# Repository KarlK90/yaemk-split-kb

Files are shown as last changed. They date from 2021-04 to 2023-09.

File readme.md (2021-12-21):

<!--
SPDX-FileCopyrightText: 2021 Stefan Kerkmann <karlk90@pm.me>

SPDX-License-Identifier: CC-BY-SA-4.0
-->

# Yet Another Ergonomic Mechanical Keyboard

[](
    https://api.reuse.software/info/github.com/KarlK90/yaemk-split-kb)

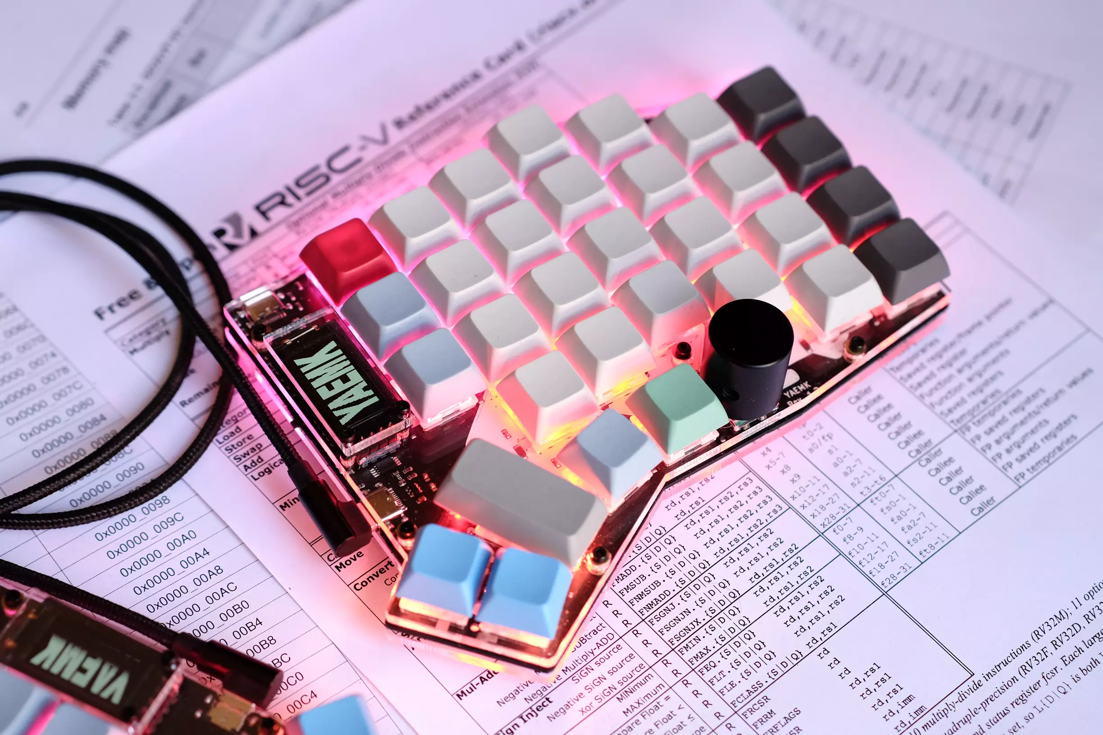
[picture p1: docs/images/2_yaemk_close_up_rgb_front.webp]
YAEMK Front


# [>>> VISIT THE WEBSITE <<<](https://karlk90.github.io/yaemk-split-kb/)

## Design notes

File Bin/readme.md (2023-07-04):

<!--
SPDX-FileCopyrightText: 2021 Stefan Kerkmann <karlk90@pm.me>
SPDX-License-Identifier: CC-BY-SA-4.0
-->

# Test Firmware Files

These firmware images are meant for easy testing purposes
only when building your own YAEMK.
Successfully flashed firmware will have:
- QWERTY layout
- Both Switch and Backlight LEDs are in rainbow mode
- Potentiometers are used for scrolling
- OLED display shows "YAEMK" logo

## Flashing ARM

After connecting the board to PC nothing will show up. On a Linux system you
can see following errors in `dmesg`:

    [   73.941437] usb 1-4: device descriptor read/64, error -71

The board need to be switched to DFU Mode in which it can be flashed:
* Hold Reset/DFU switch with USB-cable plugged in
  until the keyboard registers as `STMicroelectronics STM Device in DFU Mode`
* Flash firmware with dfu-util using this command:
  * `dfu-util -d 0483:df11 -s 0x08000000:leave -D karlk90_yaemk_arm_default.bin -w`

If `dfu-util` shows error that multiple DFU were found. Then, find one with
"Internal Flash" in name:

    > sudo dfu-util --list | grep "Internal Flash"
    Found DFU: [0483:df11] ver=2200, devnum=9, cfg=1, intf=0, path="1-4", alt=0, name="@Internal Flash  /0x08000000/128*0002Kg", serial="206B306A2034"
                                                      ^^^^^^              ^^^^^

Add `-i` and `-a` arguments with -i set to `intf` value and -a set to `alt`
value:

    > sudo dfu-util -d 0483:df11 -s 0x08000000:leave -D karlk90_yaemk_arm_via.bin -w -i 0 -a 0

## Flashing RISC-V

**You need a recent version of `dfu-util`
that has a fix for the DFU bootloader of the GD32VF103.
Follow these [instructions](
http://dfu-util.sourceforge.net/build.html) for your OS.**

* Hold the Reset/DFU switch with the USB cable plugged in,
  detach cable and re-plug immediately release the button shortly after.
  Your keyboard shows up as `GDMicroelectronics GD32 DFU Bootloader`.
* Flash firmware with dfu-util using this command:
  * `dfu-util -d 28e9:0189 -s 0x08000000:leave -D karlk90_yaemk_riscv_default.bin -w`

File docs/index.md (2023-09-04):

<!--
SPDX-FileCopyrightText: 2021 Stefan Kerkmann <karlk90@pm.me>

SPDX-License-Identifier: CC-BY-SA-4.0
-->

# Features of the YAEMK

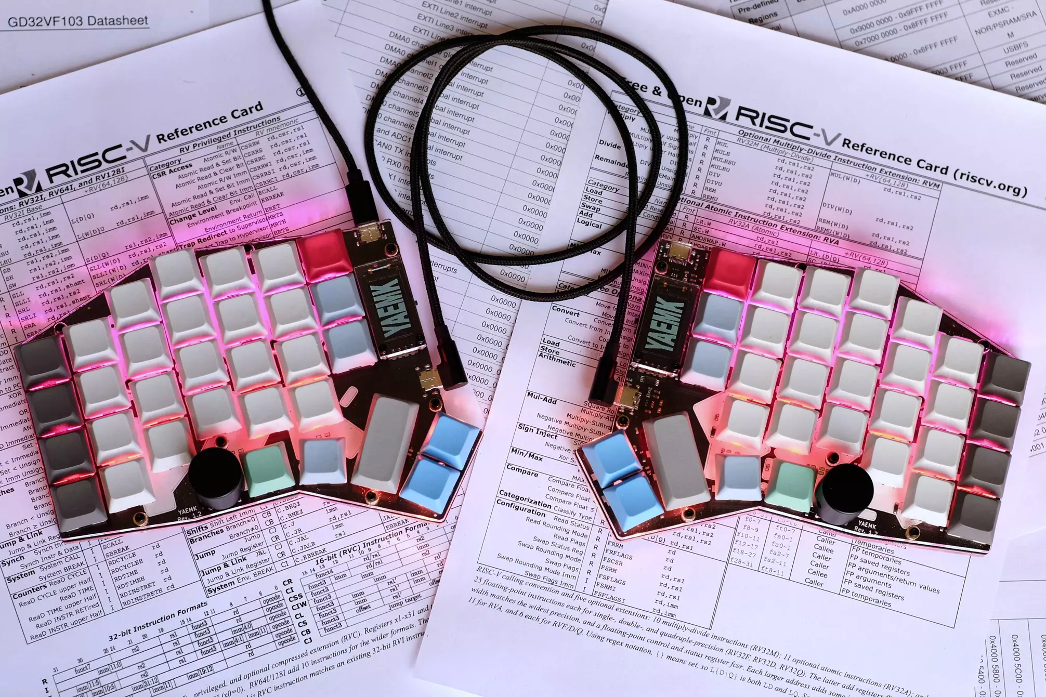
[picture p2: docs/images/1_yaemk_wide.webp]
YAEMK wide view

YAEMK close up front
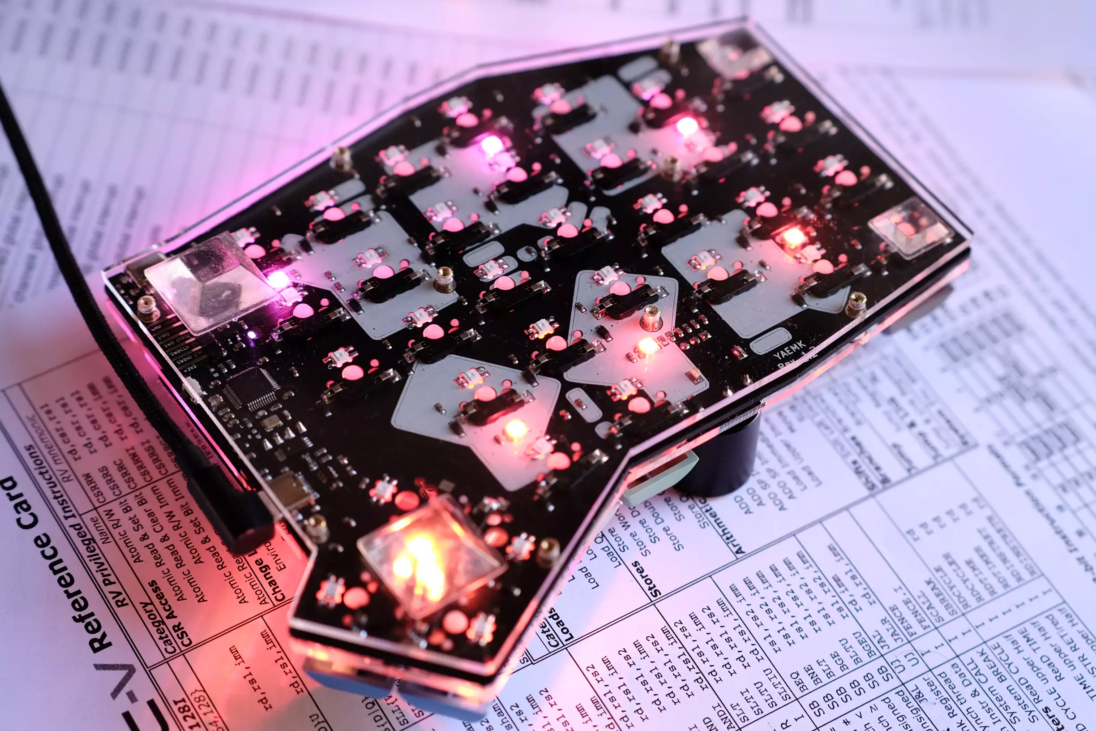
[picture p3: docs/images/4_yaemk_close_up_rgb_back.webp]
YAEMK close up back


* Split-Keyboard with 5 rows by 8 columns matrix with columnar stagger.
  Key layout testers for print ([A4](yaemk_layout_tester_a4.pdf)
  and [Letter](yaemk_layout_tester_letter.pdf)) available!
* All 64 to 66 Keys are MX-compatible and hot-swapable.
* The thumb-cluster is configurable in 4 different configurations,
  just solder the hot-swap sockets to your needs.
  * 4x1u, 2x2u, 2u+2x1u or 2x1u+2u configuration possible.
  * Inspired by the marvelous [Kyria](
    https://splitkb.com/collections/keyboard-kits/products/kyria-pcb-kit)
    from Thomas Baart!
* On-board ARM microcontroller (STM32F303CCT6) or RISC-V microcontroller (GD32VF103CBT6)
  * **Worlds first RISC-V (Split-)Keyboard!**
* Fully supported by QMK Firmware
* Per-Key RGB back lighting with 66 easy to solder SK6812-mini-e LEDs
* Underglow RGB with 14 SMD SK6812-mini LEDs
* USB-C Hot-plugable sockets for USB connection,
  and split communication between the halves
* Two 0.96" OLED displays for comprehensive information (I2C SH1107 64x128 Pixel)
* 2 x Rotary encoders for scrolling, volume changes etc.
* On-board 64KB I2C EEPROM for settings, keymaps etc.
* Open-Source, single PCB design for both sides.
  * PCB SMT assembly files for JLCPCB in the repo!
* 2-plate acrylic case files available.

## Table of contents

* TOC
{:toc}

## YAEMK Key layout testers

Key layout

Find out if building a YAEMK fits your hands, available in:

* [A4 Key layout tester](yaemk_layout_tester_a4.pdf)
* [Letter Key layout tester](yaemk_layout_tester_letter.pdf).

## Thumbcluster configurations

Four thumbcluster configurations are possible,
depending on the location of the soldered hot swap sockets.
Every configuration has a dedicated top plate for the case in the repository.

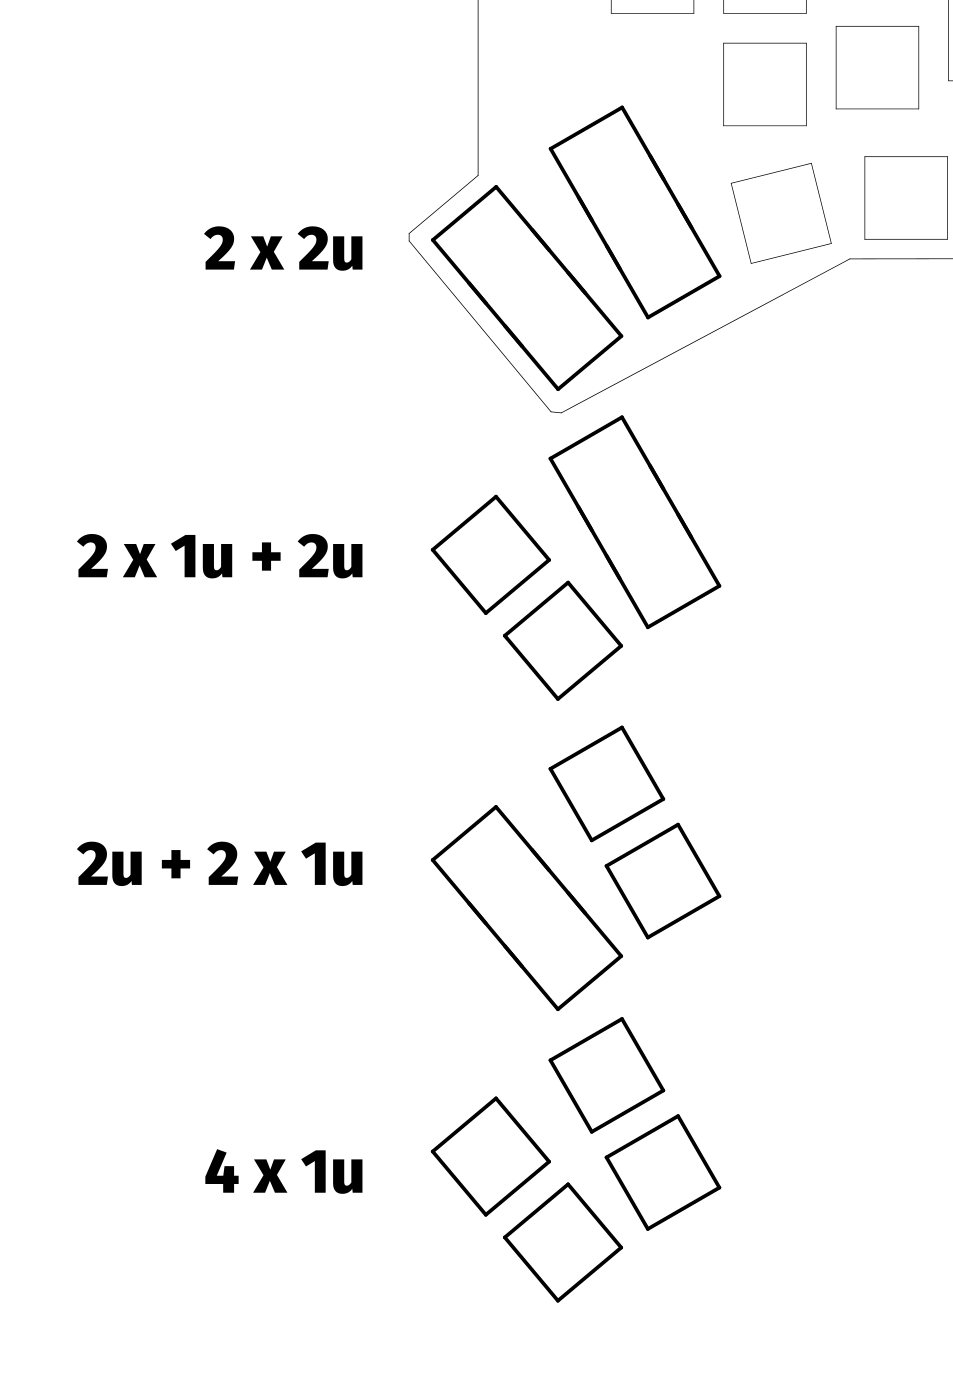
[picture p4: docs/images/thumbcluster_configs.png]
Supported thumbcluster configurations


# Build Guide

**DISCLAIMER: At the time of writing (11th of May 2021),
there is a world wide, on-going semiconductor shortage.
Both MCUs of the YAEMK,
the [STM32F303CCT6](
https://www.oemsecrets.com/compare/1/EUR/STM32F303CCT6) and
[GD32VF103CBT6](https://www.oemsecrets.com/compare/1/EUR/GD32VF103CBT6)
are affected by this shortage
and are out of stock.
The GD32VF103CBT6 can be sourced from devboards like the Sipeed Longan Nano,
but desoldering requires a hot air station.
Also the GD32VF103 requires installing a [GCC RISC-V toolchain](
https://www.embecosm.com/resources/tool-chain-downloads/#riscv-stable),
a recent `dfu-util` with fixes for the DFU bootloader.**

The complete design including [schematics](https://github.com/KarlK90/yaemk-split-kb/tree/main/PCB),
[gerbers](https://github.com/KarlK90/yaemk-split-kb/tree/main/PCB/gerbers),
[pcb smt assembly files](https://github.com/KarlK90/yaemk-split-kb/tree/main/PCB/assembly)
and a [acrylic plate case](https://github.com/KarlK90/yaemk-split-kb/tree/main/Case)
are open source and available in the repository.
The complete project can be opened with the open source [KiCad EDA](https://www.kicad.org/).

> **If you have never soldered before,
> the YAEMK will be quite a challenge.
> Therefore it is recommended to buy yourself some SMD soldering practice kits
> and learn it beforehand.**

## 1 The Boards

Building your own YAEMK involves ordering the PCBs
from [JLCPCB](https://jlcpcb.com/) with PCB SMT assembly,
so nearly all components come pre-soldered.
Only through hole components, tactile-switches,
connectors and SMD components have to be soldered by you.
It is crucial to understand that the YAEMK pcb is flip able,
which means that every circuit board
can be turned once into the left or right side of your keyboard.
Depending on right or left handedness of the PCB
these components have to be soldered either on the front or back side of the pcb.
The whole process is documented in detail below.
The tools you will need are a good quality pair of tweezers,
flux, leaded solder and a temperature controlled soldering iron,
a hot air station is recommended but not strictly necessary.
For easy component location and sourcing of parts,
it is recommended to use the [interactiv HTML BOM](./yaemk_rev_1_2.html).

<iframe src="./yaemk_rev_1_2.html" width="100%" height="500px"></iframe>

### Ordering process

If you have never ordered PCBs with assembly from [JLCPCB](https://jlcpcb.com),
I highly recommend watching the steps from Phil’s Lab
in the [KiCad STM32 + USB + Buck Converter PCB Design and JLCPCB Assembly](
https://www.youtube.com/watch?v=C7-8nUU6e3E&t=9872s) video.
The default settings are mostly fine;
The changes you want to pick are the following:

#### PCB

* Use the [gerbers.zip](https://github.com/KarlK90/yaemk-split-kb/tree/main/PCB/gerbers.zip)
  file from the PCB folder for upload.
* The Gerber preview has timeouts from time to time when uploading to JLCPCB.
  Just fill a width of `166mm` and a height of `131mm`.
* 2 Layers (The video has a 4 Layer board)
* PCB Oty: As much as you like
* PCB Color: Black
* No impedance control (Option only shown in the video)
* Surface Finish:
  HASL(with lead) if you want the easiest soldering experience,
  or LeadFree HASL.
  For extra bling-bling choose ENIG gold finish.
* Remove Order Number: Yes

#### SMT Assembly

**ATTENTION: At the time of writing (11th of May 2021),
there is a world wide on-going semiconductor shortage,
both MCUs of the YAEMK the [STM32F303CCT6](
https://www.oemsecrets.com/compare/1/EUR/STM32F303CCT6)
and [GD32VF103CBT6](https://www.oemsecrets.com/compare/1/EUR/GD32VF103CBT6)
are affected of this shortage and are out of stock.
Therefore you currently can not order the pcb with the MCU pre-soldered.
I was not able to correct and confirm the MCU orientation,
it is likely rotated in correctly.
As soon as the MCU is in stock again this will be addressed.**

* Assemble top side
* SMT Oty: As much as you like
* Tooling holes: Added by Customer
* Add BOM file:
  the file is [PCB/assembly/YAEMK_bom.csv](
  https://github.com/KarlK90/yaemk-split-kb/blob/main/PCB/assembly/YAEMK_bom.csv)
  * If the default EEPROM and Opamp are out of stock,
    you can try the alternate BOM file:
    the file is [PCB/assembly/YAEMK_bom_alternate_eeprom_and_opamp.csv](
    https://github.com/KarlK90/yaemk-split-kb/blob/main/PCB/assembly/YAEMK_bom_alternate_eeprom_and_opamp.csv)
* Add CPL file: the file is [PCB/assembly/YAEMK-top-pos_corrected.csv](
  https://github.com/KarlK90/yaemk-split-kb/blob/main/PCB/assembly/YAEMK-top-pos_corrected.csv)
* If you want the GD32VF103 MCU,
  deselect `U5 STM32F303CCTx` on the *Select Parts* page.
  You have to source and solder the GD32VF103 yourself.

After placing your order you can proceed ordering the missing parts from [LCSC](https://lcsc.com/),
as they are both part of the same company,
you [can save shipping costs](https://www.lcsc.com/faqs?id=140)
when specifying your JLCPCB order number.

### Additional bill of materials for one complete Keyboard

All components that are NOT pre-soldered by [JLCPCB](https://jlcpcb.com/)
are listed in this table and have to be bought and assembled by you.
Switches and Keycaps are highly personal decision,
you find my recommendation at the bottom.
As I'm using a rather uncommon keyboard layout (K.O,Y) I stick to blank keycaps.

Personal recommendation of Aliexpress stores:

  - [Cool Jazz Store](https://cooljazz.aliexpress.com/store/1806079)
  - [KRepublic](https://kprepublic.aliexpress.com/store/3034003)

| Amount | Part | LCSC | Link |
| --- | --- | --- | --- |
| 4 | USB-C Socket Mid-mount | C168688 | [LCSC](https://lcsc.com/product-detail/USB-Connectors_Jing-Extension-of-the-Electronic-Co-C168688_C168688.html) or [Aliexpress](https://www.aliexpress.com/item/4000074094558.html) |
| 2 | Alps EC11 Rotary Encoder | C370986 | [LCSC](https://lcsc.com/product-detail/Coded-Rotary-Switches_ALPS-Electric-EC11E183440C_C370986.html) |
| 5 | LMV321 Opamp (Backup) | C686637 | [LCSC](https://lcsc.com/product-detail/Operational-Amplifier_PJSEMI-LMV321_C686637.html) |
| 66 | SK6812-mini-e (3228) RGB LEDs | - | [Aliexpress](https://www.aliexpress.com/item/4000475685852.html) |
| 14 | SK6812-mini (3535) RGB LEDs | - | [Aliexpress](https://www.aliexpress.com/item/33019583218.html) |
| 66 | Hotswap Kailh or Gateron Sockets | - | [Aliexpress](https://www.aliexpress.com/item/1005002037689483.html) |
| 2 | Encoder Knob | - | [Splitkb](https://splitkb.com/collections/keyboard-parts/products/matte-aluminium-encoder-knob) or [Aliexpress](https://www.aliexpress.com/item/32893184848.html) or [Aliexpress](https://www.aliexpress.com/item/32810522800.html) |
| 2 | 0.96" SSD1107 64x128 Display | --- | [Aliexpress](https://www.aliexpress.com/item/1005002891710621.html) |
| 2 | Blue 0603 Power LED | C72041  | [LCSC](https://lcsc.com/product-detail/Light-Emitting-Diodes-LED_0603-Blue-light_C72041.html) |
| 2 | Reset/DFU Switch | C393942 | [LCSC](https://lcsc.com/product-detail/Tactile-Switches_SHOU-HAN-TS24CA_C393942.html) |
| 2 | Display Socket | C358718 | [LCSC](https://lcsc.com/product-detail/Pin-Header-Female-Header_MINTRON-MTF185-104SY1_C358718.html) |
| 2 | Debug Pinheader (optional) | C56816  | [LCSC](https://lcsc.com/product-detail/Pin-Header-Female-Header_BOOMELE-Boom-Precision-Elec-2-54-1-6PHeader_C56816.html) |
| 66 | Switches (depending on Thumbcluster) | - | Personal recommendations [Clicky - Box Yellow](https://www.aliexpress.com/item/1005001684056035.html) or [Tactile - Boba U4 RGB](https://www.aliexpress.com/item/1005001809357064.html) or [Linear - Boba Bobbagum](https://www.aliexpress.com/item/1005001985634467.html) |
| 64-66  | 1u Keycaps (depending on Thumbcluster) | - | e.g. 1u XDA Profile caps [Aliexpress](https://www.aliexpress.com/item/1005004021955113.html) |  |
| 0-4 | 2u Keycaps (depending on Thumbcluster) | - | e.g. 2u XDA Profile caps [Aliexpress](https://www.aliexpress.com/item/1005001376888502.html) |

**Tip: Buy some excess LEDs as they are heat sensitive!**

### Placement of hotswap sockets for thumbcluster

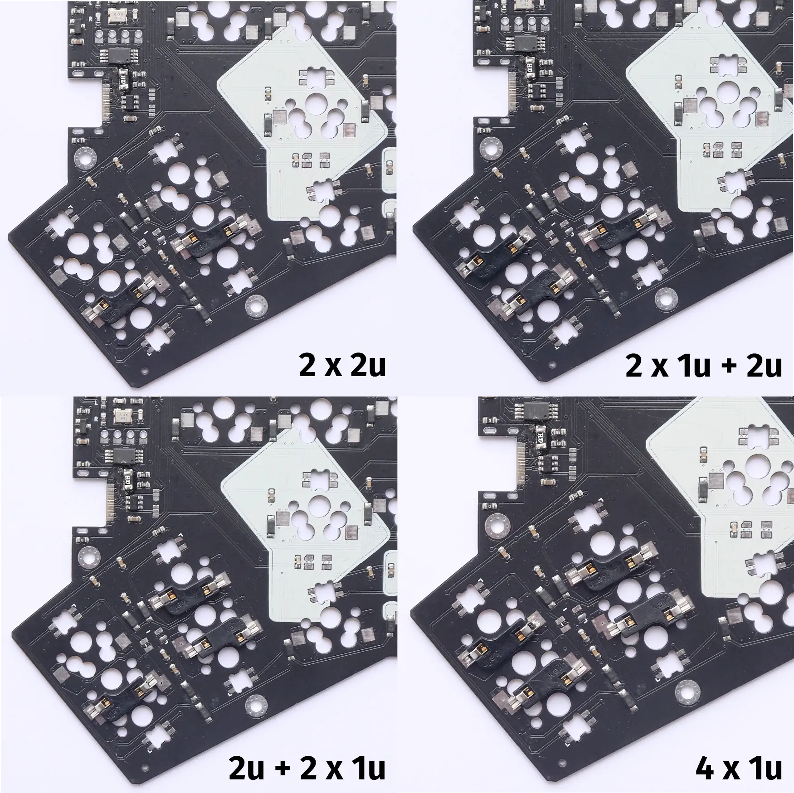
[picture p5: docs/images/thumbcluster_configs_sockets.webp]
Thumbcluster configurations sockets


### Correct orientation of hotswap sockets

Do not obstruct the middle hole with the hotswap sockets or switches will not fit!

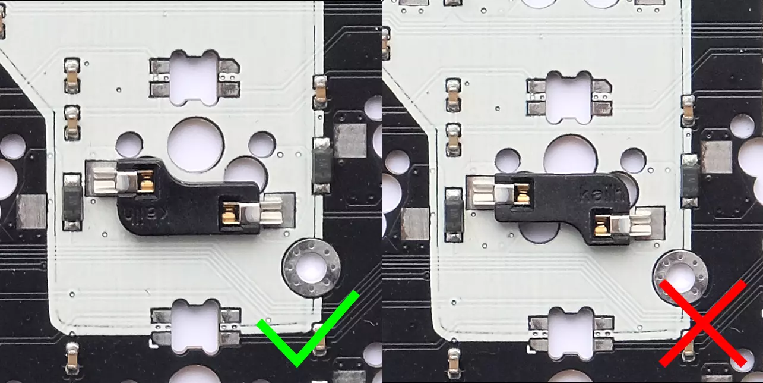
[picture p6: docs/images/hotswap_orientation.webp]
Correct orientation hotswap sockets


### Correct orientation of rgb leds

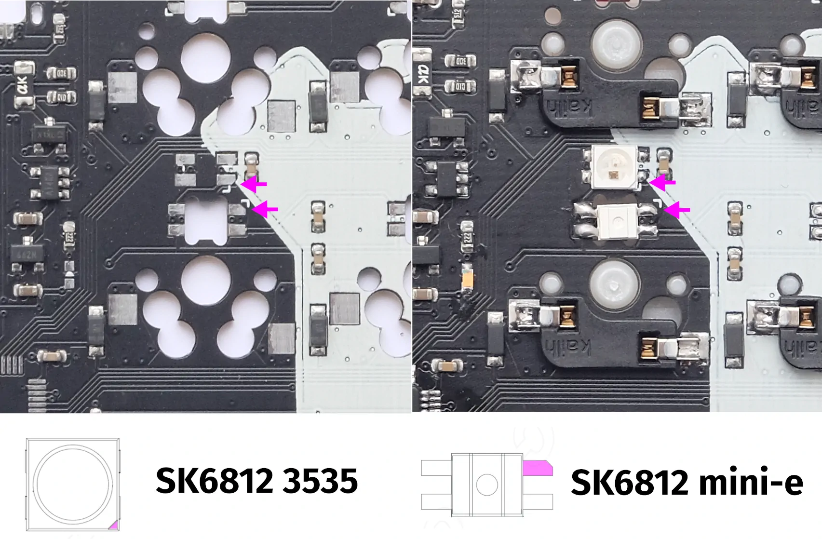
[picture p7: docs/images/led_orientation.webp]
Correct orientation of rgb leds


Every led has little chamfer that indicates the correct orientation,
match it with the chamfer on the pad of the PCB
and the little white triangle silk screened next to the pad.
Two types of leds are used on the YAEMK the first sk6812 3535 are for underglow,
there are 7 per side in total and distributed along the edges of the PCB,
it is the upper led in the picture.
They shine down on the surface the keyboard rests on.
The second type are sk6812-mini-e leds for per-key backlighting,
it is the lower led in the picture.
They shine up through the PCB,
away from the surface the keyboard rests on.

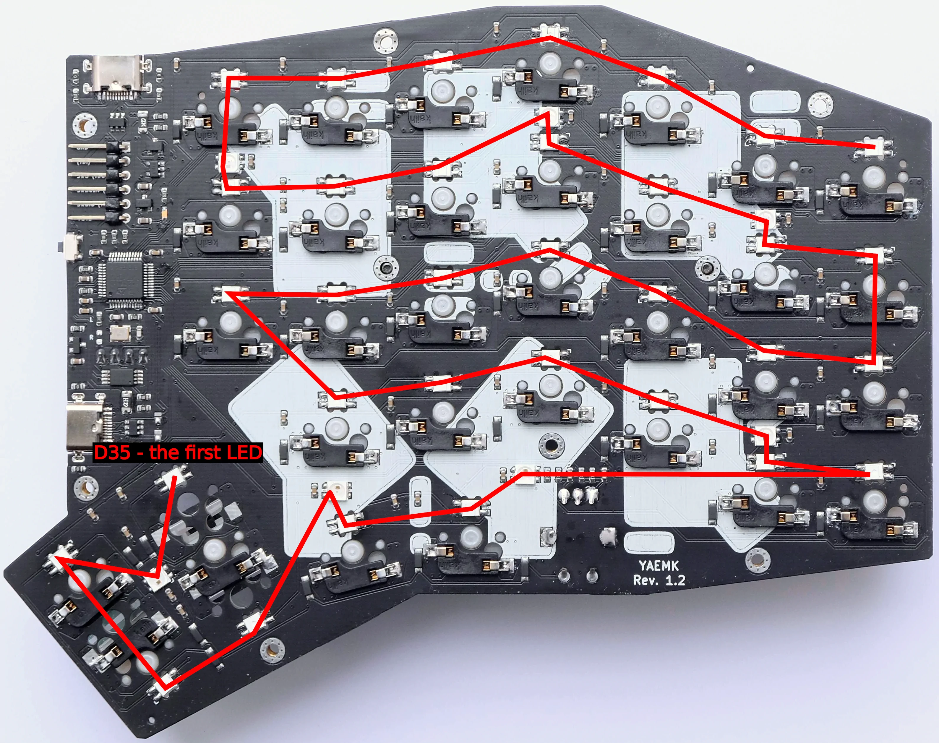
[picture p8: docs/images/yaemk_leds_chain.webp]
LED chain orientation


### Modification of SH1107 display modules

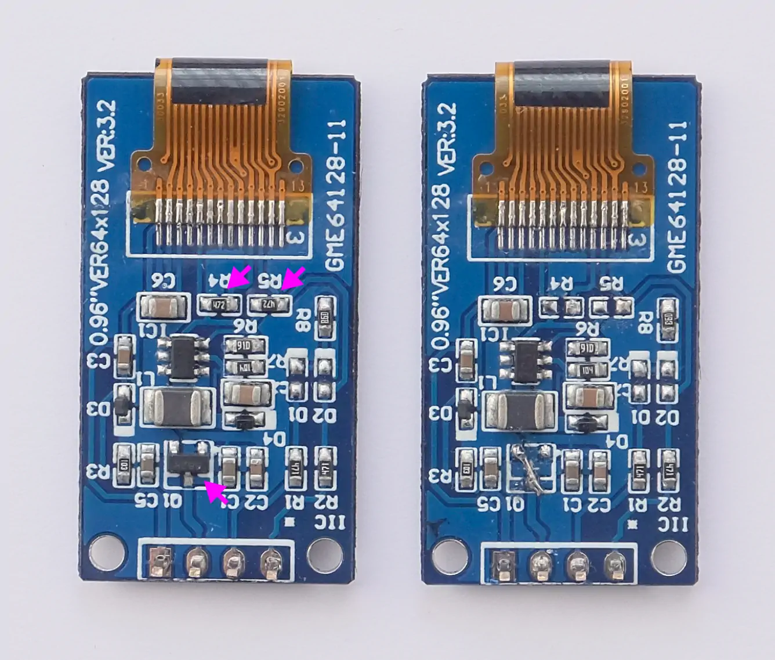
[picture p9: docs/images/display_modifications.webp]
SH1107 display module modifications


Remove the pull-up resistors `R4` and `R5` with your soldering iron,
these redundant as the YAEMK already has pull-ups in place.
Remove the low drop out (LDO) regulator `Q1`
by cutting its legs or with your soldering iron
and bridge the terminal by soldering a small piece of wire in place.
The LDO is redundant and serves no function,
as the YAEMK already supplies the display with stabilized 3.3V VDD.

### Step-by-step Instructions

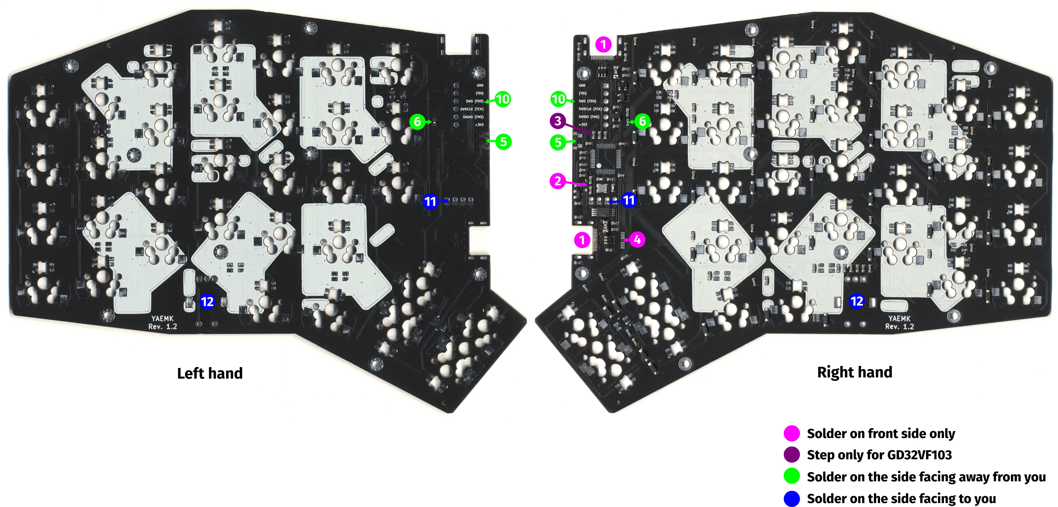
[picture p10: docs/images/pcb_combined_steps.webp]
PCBs with Step-by-step instructions


*Note: the picture shows pcbs without an mcu.*

> Emphasized text like `P1 and P2` are the component references,
> you can find them in the schematic and interactive bom.

1. Solder USB-C Sockets for USB connection and Split communications. `P1 and P2`
    * Make sure to apply enough solder
      and thoroughly wet the pins that secure the socket with the PCB.
2. Remove handedness selection resistor `R24 or R25`
    * The handedness, meaning if it is the right or left side of the keyboard,
      is determined by these resistors.
      PCBs come with both resistors soldered in place from JLCPCB.
      Keep the resistor for the side you want this PCB to be,
      e.g. keep resistor `R25` next to the little R
      if this PCB should be the right side of the keyboard
      and remove resistor `R24` next to the little L.
3. *(GD32VF103 only)* Remove USB D+ pullup resistor `R20`
4. Close split communication solder jumpers `JP1 and JP2`
    * Both halves of the YAEMK communicate via a full-duplex USART connection
      over a USB-C cable (we re-purpose the USB cable for this).
      For this to work the TX lines of one halve
      have to be connected with the RX line of the other halve.
      That's what the solder bridge is for,
      to reroute the TX line of one halve into the RX line of the other.
    * Connect the bottom pad with the middle pad on both jumpers
      via a solder bridge on the left side of the keyboard.
    * Connect the top pad with the middle pad on both jumpers
      via a solder bridge on the right side of the keyboard.
5. Solder Reset/DFU Switch on the side facing away from you. `S32`
6. Solder power LED on the side facing away from you. `D70`
    * A little triangle shows the orientation of the LED on the board,
      match this triangle with the triangle on the bottom of the led.
7. Flash the [testing firmware provided](
    https://github.com/KarlK90/yaemk-split-kb/tree/main/Bin)
    and test for successful usb connection.
8. Solder RGB LEDs on the side facing away from you.
    Make sure to [correctly orient](#correct-orientation-of-rgb-leds) them,
    as they are not the same orientation all the time.
    Use the interactive BOM when in doubt. `D35 to D76`. Check that all LEDs
    are working by connecting the board to USB (the firmware from step 7 turns
    on all the LEDs). Note that as LEDs are [connected in
    chain](#correct-orientation-of-rgb-leds)  - one dead LED leads
    to all subsequent leds being off.
9. Solder MX Hotswap Sockets on the side facing away from you.
    Decide for a [thumbcluster configuration](#placement-of-hotswap-sockets-for-thumbcluster).
    Make sure to [correctly orient](#correct-orientation-of-hotswap-sockets) them.
    `S1 to S31`
10. *(Optional)* Solder Debug Header on the side facing away from you.
    `J1`
11. Solder Display Socket on the side facing to you.
    `P3`
    * Bridge the pads next to the through holes when soldering to close the contact.
12. Solder Rotary Encoder on the side facing to you.
    `SW1`
13. Clean the Board from any residues with alcohol.
14. Modifiy the SH1107 displays by removing the pull-ups
    and the LDO as [demonstrated](#modification-of-sh1107-display-modules).
15. Trim the plastic and the pin header of the display
    so that the pcb of the display sits flush on the display socket.
16. *(Optional)* Paint the edges of the pcb with a black marker pen.
17. *(Optional)* Paint the blue display frame and pcb edges with a black marker pen.
18. Test board for full operation, see Troubleshooting notes below in case of errors:
    * Displays show YAEMK logo on startup on both halves.
    * Successful USB connection of both halves to the pc,
      regardless of plug orientation.
      Make sure that the default Layer designator "QWERTY" on the OLED
      is surrounded by two small dots.
      This indicates that this side has a USB connection.
    * Successful split connection between both halves,
      regardless of plug orientation.
      If both sides claim to have a USB connection
      ("QWERTY" on the OLED is surrounded by two small dots on both sides)
      altough one is clearly powered by the other
      and has no direct USB connection to the PC
      (the peripheral half) jump to [Peripheral half show USB connection](
      #peripheral-half-shows-usb-connection).
    * Key presses for all keys are registered,
      for testing bridge the terminals of the hotswap-sockets with a piece of wire.
    * All leds fully light up, no flickering when slightly bending the pcb.
    * Rotary encoders register motion.
    * Reset+DFU tactile switch resets the board on short press
      and enters DFU bootloader on long press
      (see GD32VF103 specific notes in Firmware section).

### Finished left handed PCB for reference, switches are already installed

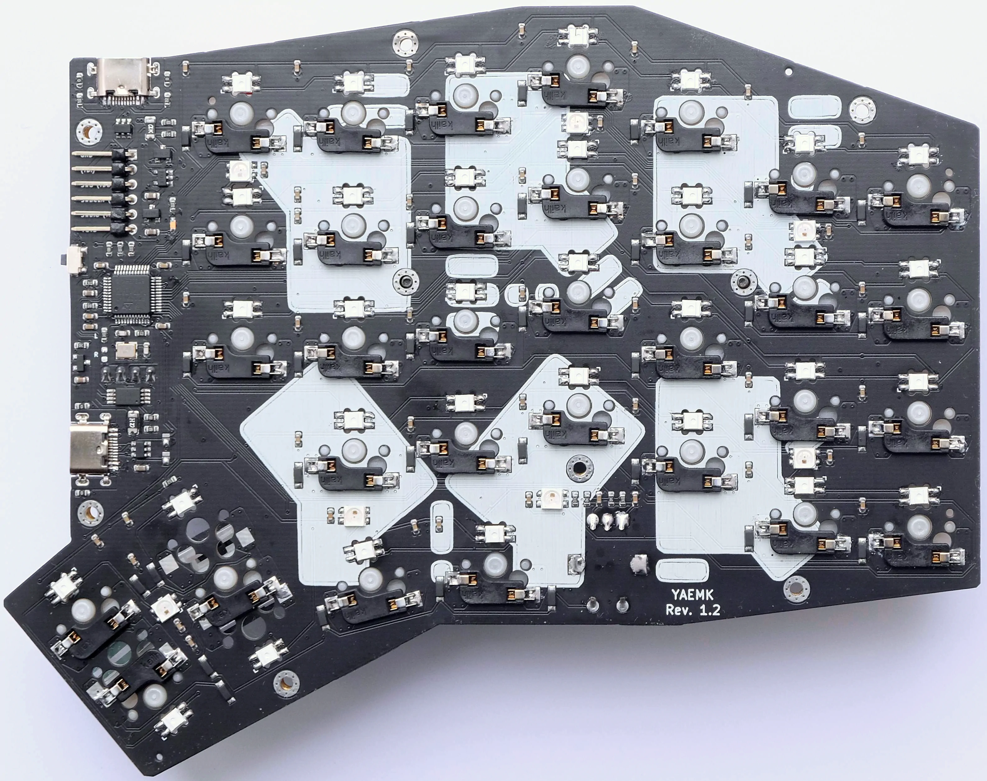
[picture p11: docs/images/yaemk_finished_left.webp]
YAEMK finished left side


## Troubleshooting

### General debugging and logs

QMK offers debug logs via USB connection,
so if your YAEMK already connects successfully over USB you can use these.
Follow the official [QMK guide](https://docs.qmk.fm/#/faq_debug)
and apply these changes to the firmware.

In [`rules.mk`](
https://github.com/KarlK90/qmk_firmware/blob/ac4591f9e417bdcc48421241e5b26c6b8ff710da/keyboards/karlk90/yaemk/rules.mk)
change these options:

```makefile
CONSOLE_ENABLE     = yes
```

and in [`yaemk.c`](
https://github.com/KarlK90/qmk_firmware/blob/ac4591f9e417bdcc48421241e5b26c6b8ff710da/keyboards/karlk90/yaemk/yaemk.c)

```c
void keyboard_post_init_user(void) {
    // Customise these values to desired behaviour
    debug_enable   = true;
    debug_matrix   = true;
    debug_keyboard = true;
    debug_mouse    = true;
}
```

### Peripheral half shows USB connection

In rare cases,
the USB connection detection malfunctions,
and the peripheral half it is connected to and powered by the primary half,
claims that it has a USB connection as well.
This is the case if "QWERTY" on the OLED
is surrounded by two small dots on both sides.
In this case the split connection does not work
and the primary half feels sluggish.
The root cause is often a malfunctioning LMV321 Opamp with designator `U6`.
The highly recommended fix is to replace it with a new one.
A temporary workaround is disabeling the USB detection in software
by commenting out the [`is_keyboard_master()`](
https://github.com/KarlK90/qmk_firmware/blob/ac4591f9e417bdcc48421241e5b26c6b8ff710da/keyboards/karlk90/yaemk/yaemk.c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)
in [`yaemk.c`](
https://github.com/KarlK90/qmk_firmware/blob/ac4591f9e417bdcc48421241e5b26c6b8ff710da/keyboards/karlk90/yaemk/yaemk.c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)
and afterwards recompiling and flashing the firmware.

### Sluggish keypresses / Keys not registered

Make sure to have OLED screens and the EEPROM in place
when you use the default firmware,
otherwise heavy timeouts will lead to missed keypresses.
If you don't want to use OLED screens and/or EEPROM,
change these defines in  [`rules.mk`](
https://github.com/KarlK90/qmk_firmware/blob/ac4591f9e417bdcc48421241e5b26c6b8ff710da/keyboards/karlk90/yaemk/rules.mk)
and recompile the firmware.

```makefile
EEPROM_DRIVER      = transient
OLED_DRIVER_ENABLE = no
```

### No USB connection

Make sure that you soldered the pins of the USB-C sockets to the pads,
if in doubt reflow with solder and flux.
Test for continuity with a multimeter on the d+ and d- lines
between the legs of the ESD protection diode `U3`
and a plugged in USB-C cable.

### No split communication

Make sure that you soldered the pins of the USB-C sockets to the pads,
if in doubt reflow with solder and flux.
Test for continuity with a multimeter on the TX and RX lines
between the legs of the ESD protection diode `U4` on both halves,
connecting them with a USB-C cable.
Make sure that you closed the solder bridges
in opposite fashion on both halves,
i.e. the left halve bridged the left pads with solder bridges
and the right halve bridged the right pads with solder bridges.

### No power

Check for shorts between VDD and GND with a multimeter.
Make sure that the USB-C sockets are soldered the their pads,
if in doubt reflow with solder and flux.

### LED chain broken or flickering LEDs

Check the correct orientation of the rgb led first,
correct if necessary.
If correct,
try to apply some pressure to the first LED that doesn't work in the chain,
if this turns on the LED you have cold solder connection -
reflow the LED.
Should that not work,
try the last LED in the chain that does work properly,
if that turns on other LEDs in the chain,
the problem was the again a cold solder connection -
reflow the LED.
If all that doesn't help try to re-solder these leds,
even if applying pressure didn't help.
If that doesn't solve the problem one of the leds is dead,
replace with a new one.

## 2 Acrylic plate case

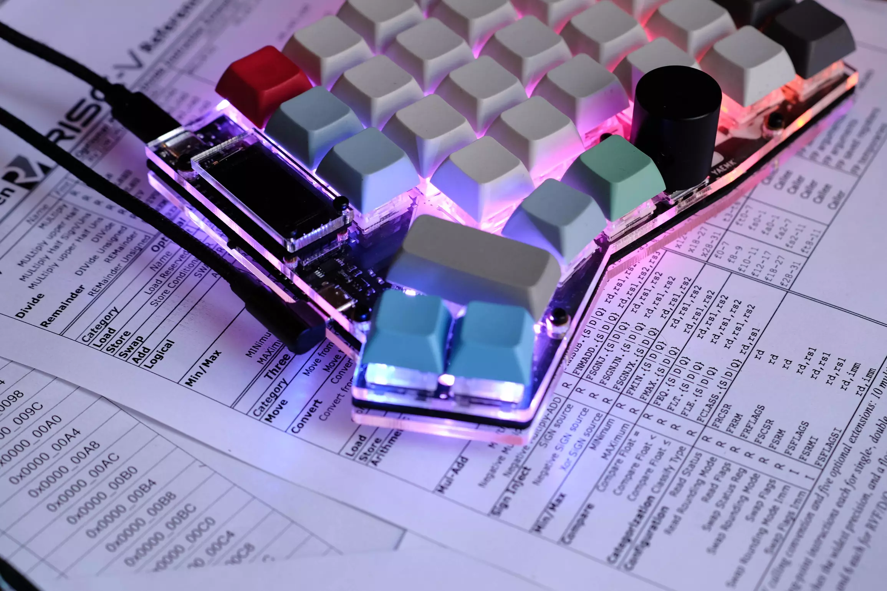
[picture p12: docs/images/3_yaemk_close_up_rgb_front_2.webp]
YAEMK close up front 2


The official YAEMK case consists of one top and bottom plate
and a display cover for each side and is made out of 3mm acrylic plates.
All designs are flipable,
so each plate can be used for the left or right side of the keyboard.
For each thumbcluster configuration a specific top plate was designed,
the bottom plate is universal for all configurations.
You can find the [SVG files](https://github.com/KarlK90/yaemk-split-kb/tree/main/Case)
in the repo once without kerf and once with a kerf of 0.1mm for laser cutting.
Cast Acrylic is highly recommended for its clearer appearance and sturdiness,
extruded acrylic is brittle and prone to cracks!

### Case principle

Case principle

The pcb is clamped by the brass M3 insert and M2 standoff
by tightening the M2 screw which only has grip in the M2 standoff.
The Display is clamped between the cover and the M2 standoffs
of the top case and display socket.
Both brass inserts are melted flat to the surface into the acrylic plates
using a soldering iron set to 160c and a pointed tip, like the T12-I.
Watch this [video](
https://youtu.be/XNGXNDp0mMw?t=114) to get a understanding of the process.

### Bill of material for one case

| Amount | Part |
| --- | --- |
| 2 | YAEMK Top plate |
| 2 | YAEMK Bottom plate |
| 2 | YAEMK Display cover |
| 8 | Transparent rubber buffers |
| 22 | M2x12mm Screws |
| 22 | M2x5x3.2mm Round brass standoffs |
| 18 | M2x5mm Round brass washers |
| 18 | M3x5x4.6mm Round brass insert nuts |

> All size designations for the standoffs and insert nuts are `(dxHxD)`. `d` = inner diameter, `H` = height and `D` = outer diameter.

### Step-by-step instructions

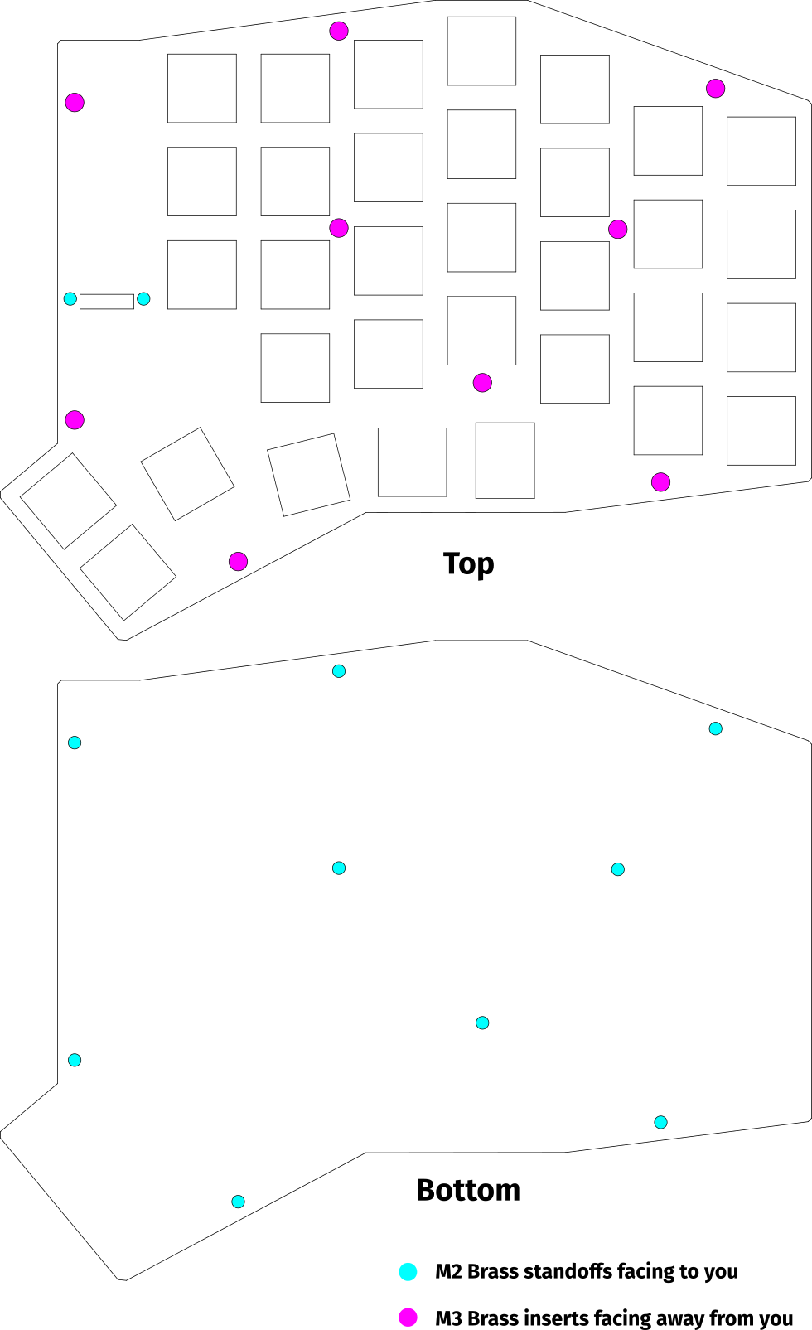
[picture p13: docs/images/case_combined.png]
Case assembly guide


**Pay attention to make all inserts flush with the surface!
If acrylic obstructs the inserts after insertion remove it while it is still warm.**

1. Melt M3 insert into the top plate.
2. Melt M2 standoffs for the display cover into the top plate.
3. Melt M2 standoffs into bottom plate.
4. Assemble case with display and display cover.
5. Insert switches and keycaps.

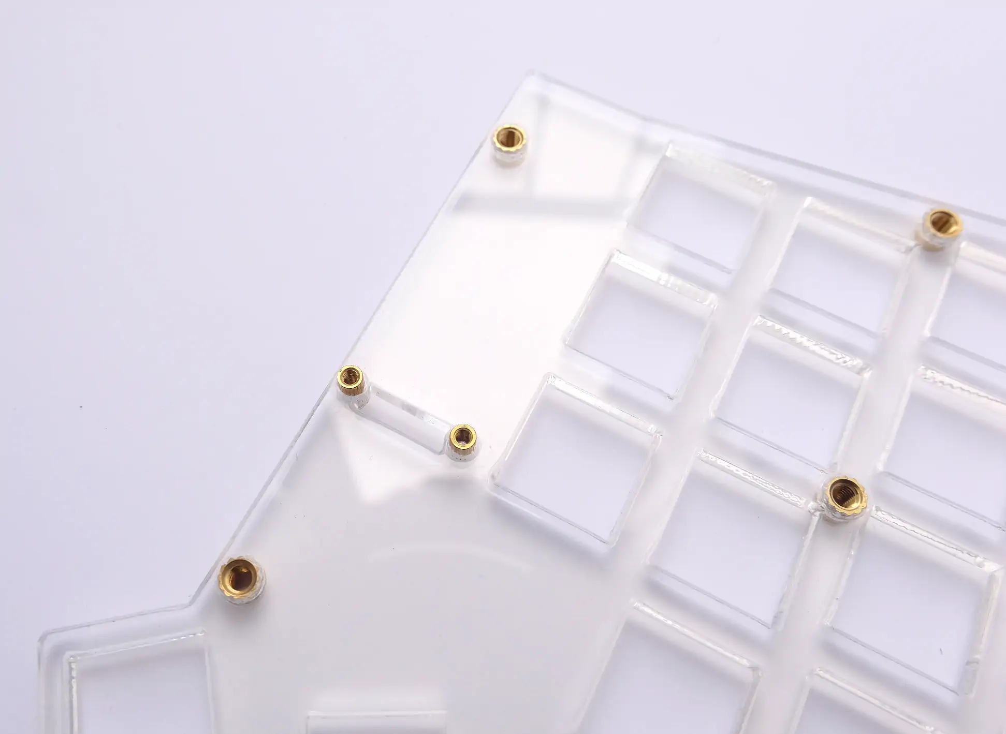
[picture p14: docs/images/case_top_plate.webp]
Close up top plate


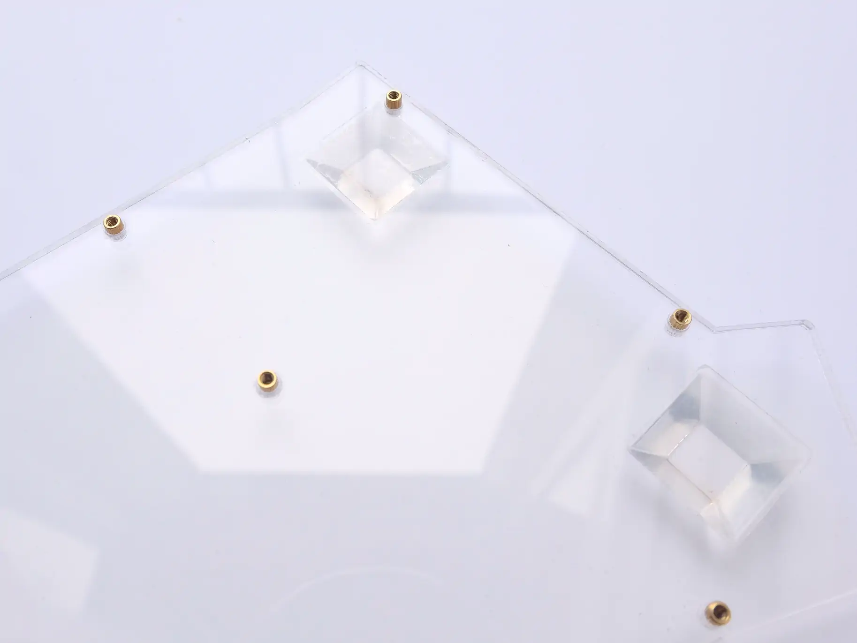
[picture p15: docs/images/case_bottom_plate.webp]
Close up bottom plate


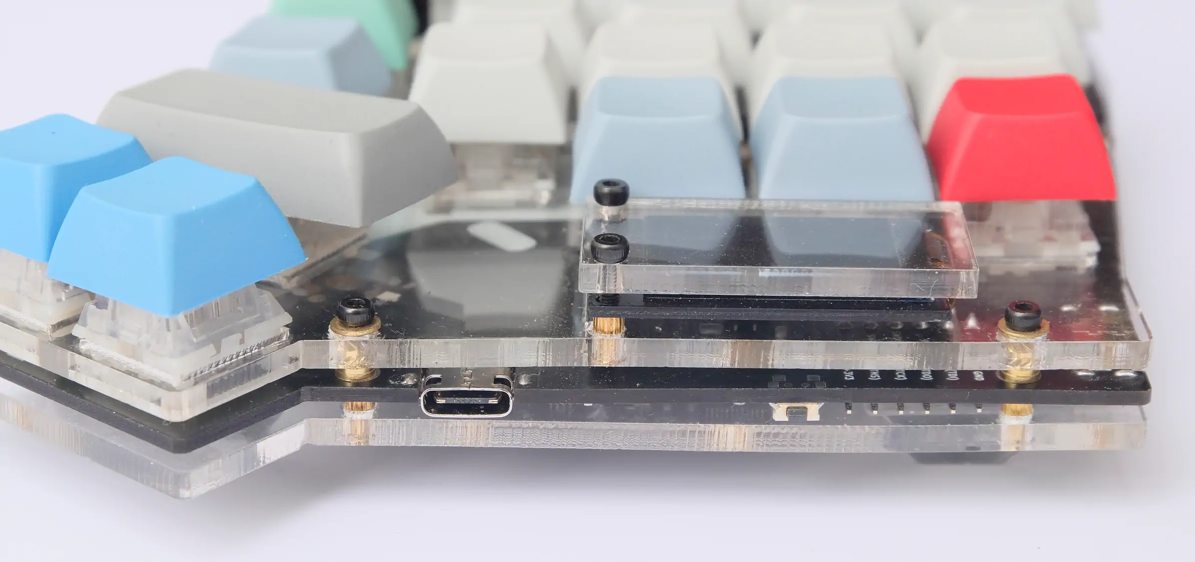
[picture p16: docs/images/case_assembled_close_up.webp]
Close up finished case


## 3 Magnetic tenting legs

Tenting can be easily added to the acrylic case
by using the magnetic tenting legs originally invented by [Manna Harbour](
https://www.reddit.com/r/MechanicalKeyboards/comments/ebf228/diy_magnetic_tent_legs/).

### Bill of material to add tenting to one case

| Amount | Part | Link |
| --- | --- | --- |
| 4 | 20mm x 3mm disc magnets | [Aliexpress](https://www.aliexpress.com/item/1005001632637670.html) |
| 4 | 20mm x 3mm countersunk ring magnets | [Aliexpress](https://www.aliexpress.com/item/1005001632871071.html) |
| 4 | 10mm M3 flat head screws | --- |
| 4 | 20mm or 25mm M3 standoffs | --- |
| 4 | M3 Thumb screws | --- |
| 8 | 6mm/8mm Round transparent rubber buffers | [Aliexpress](https://www.aliexpress.com/item/33030992785.html) |

### Step-by-step instructions

If in doubt follow the link to the article by [Manna Harbour](
https://www.reddit.com/r/MechanicalKeyboards/comments/ebf228/diy_magnetic_tent_legs/)
to get a clear idea of the tenting mechanism.

1. Glue the disc magnets to the bottom of the case,
    be careful to have them in parrallel to each other.
    I used transparent double sided adhesive tape for this.
2. Fix the countersunk ring magnets to the standoffs using the flat head screws.
3. Fix the thumb screws to the standoffs.
4. Add rubber buffers to the outer edges of the case and the thumb screws.
5. Attach the legs to the case.

## 4 Firmware

YAEMK uses the *Quantum Mechanical Keyboard Firmware (qmk)*. 
Until there is mainline support for YAEMK in QMK,
you will have to use my QMK fork.

To flash it onto your board, follow these instructions:

1. Make that you have cloned the yaemk repository,
    including its submodules with git,
    and not downloaded a release zip.
    * `git clone --recurse-submodules https://github.com/KarlK90/yaemk-split-kb.git`
2. Install the `qmk` tool.
    You can find detailed instructions in the [QMK getting started guide](
    https://docs.qmk.fm/#/newbs_getting_started).
3. Put your board into the USB-DFU bootloader mode.
    * STM32F303: Hold the Reset+DFU button,
      until your board registers as STM32 DFU bootloader
    * GD32VF103: Hold the Reset+DFU button with the USB cable plugged in,
      detach cable and re-plug.
      Immediately release the button shortly after.
4. Adjust features to your liking.
5. Flash the firmware.
    * For the ARM version: `qmk flash -kb karlk90/yaemk/arm -km default`
    * For the RISC-V version: `qmk flash -kb karlk90/yaemk/riscv -km default`

### GD32VF103 RISC-V GCC Toolchain and `dfu-util`

### Debian 11 based distributions

A fully working RISC-V GCC toolchain is shipped beginning with Debian 11
and distributions based on it,
like Ubuntu 21.04.
It can be installed with the help of `apt` or `apt-get`:

1. `sudo apt install picolibc-riscv64-unknown-elf binutils-riscv64-unknown-elf gcc-riscv64-unknown-elf`
2. Tryout if `riscv64-unknown-elf-gcc` is found
    by running `riscv64-unknown-elf-gcc --version` from a terminal/command line/console.
    If successful, you're done.

You should see an output similar to this:

```
❯ riscv64-unknown-elf-gcc --version
riscv64-unknown-elf-gcc () 10.2.0
Copyright (C) 2020 Free Software Foundation, Inc.
This is free software; see the source for copying conditions.  There is NO
warranty; not even for MERCHANTABILITY or FITNESS FOR A PARTICULAR PURPOSE.
```

### Manual Installation

At the moment,
the default QMK installation process doesn't include a RISC-V GCC toolchain.
Fortunatlly, there are pre-built toolchains available
for a all major operating systems by [EMBECOSM](
https://www.embecosm.com/resources/tool-chain-downloads/#riscv-stable)
that we can install.

1. [Download the stable GCC toolchain from EMBECOSM for your operating system.](
    https://www.embecosm.com/resources/tool-chain-downloads/#riscv-stable)
2. Unpack the toolchain archive and copy to a folder accessible to your user.
    * On Linux I used `/opt/riscv32-embecosm-ubuntu2004-gcc11.1.0`
      (moved with root privileges).
3. Add the bin folder `/opt/riscv32-embecosm-ubuntu2004-gcc11.1.0/bin`
    to your [PATH environment Variable](
    https://superuser.com/questions/284342/what-are-path-and-other-environment-variables-and-how-can-i-set-or-use-them).
    * You might need to logout and login again, afterwards.
4. Tryout if `riscv32-unknown-elf-gcc` is found
    by running `riscv32-unknown-elf-gcc --version` from a terminal/command line/console.
    If successful, you're done.

You should see an output similar to this:

```
❯ riscv32-unknown-elf-gcc --version
Copyright (C) 2021 Free Software Foundation, Inc.
This is free software; see the source for copying conditions.  There is NO
warranty; not even for MERCHANTABILITY or FITNESS FOR A PARTICULAR PURPOSE.
```

For flashing,
`dfu-util` with a version of 0.10+ is needed,
because the DFU bootloader of the GD32VF103 has a bug in it.

* **\[Linux\]** Most Linux distributions pack version 0.9 of `dfu-util`,
  if this is the case,
  you have to build it yourself following these [instructions](
  http://dfu-util.sourceforge.net/build.html).
  * To use dfu-util without root privileges,
    copy the udev rules `60-dfuse.rules` from the `doc` folder
    to your udev `rules.d` folder.
    Trigger a reload of the rules to apply them immediatly.
  *

    ```shell
    sudo cp doc/60-dfuse.rules /etc/udev/rules.d/ \
        && sudo udevadm control --reload-rules \
        && sudo udevadm trigger
    ```

* **\[Windows and MacOS\]** [pre-built](
  http://dfu-util.sourceforge.net/releases/dfu-util-0.10-binaries.tar.xz)
  versions of dfu-util 0.10 are available.
  Download, unpack and add to path like the GCC toolchain.

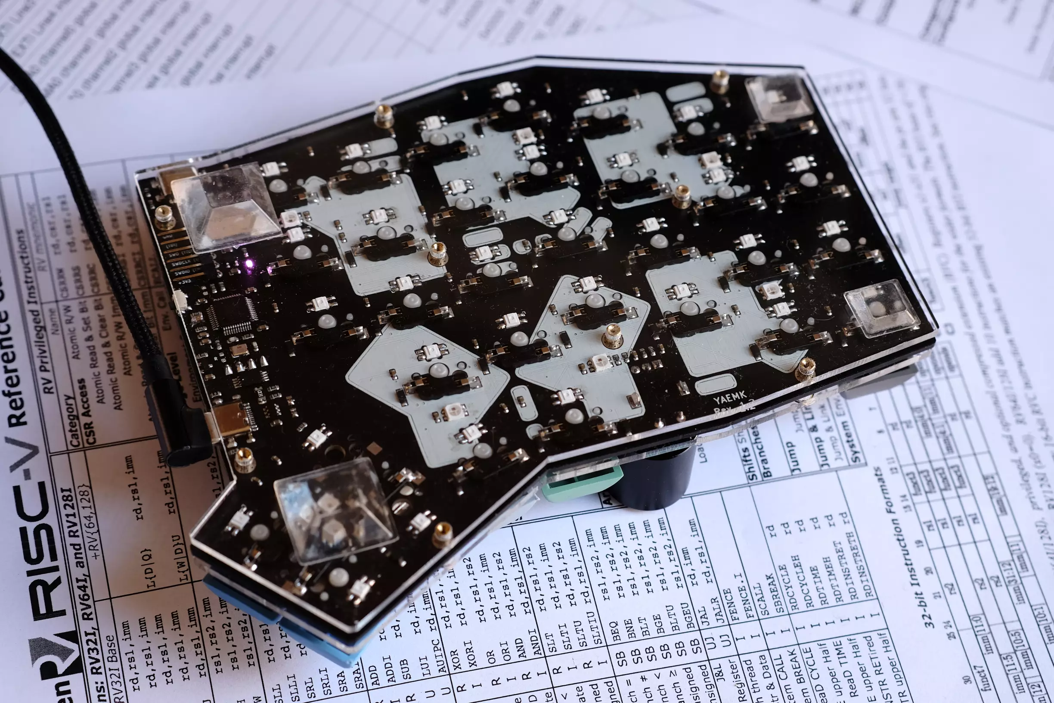
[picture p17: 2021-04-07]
docs/images/5_yaemk_close_up_plain_back.webp

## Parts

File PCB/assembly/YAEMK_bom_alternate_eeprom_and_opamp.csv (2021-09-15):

Comment | Designator | Footprint | LCSC Part #
100n | C1,C2,C39,C38,C41,C37,C54,C53,C50,C51,C49,C52,C48,C24,C7,C3,C4,C5,C6,C19,C8,C10,C9,C14,C11,C12,C22,C16,C17,C18,C15,C13,C20,C28,C21,C23,C25,C27,C30,C29,C26,C32,C33,C34,C31,C35,C36 | SMD-0603 | C14663
1u | C42 | SMD-0603 | C15849
10u | C43,C44,C45,C40 | SMD-0603 | C19702
20p | C46,C47 | SMD-0603 | C1648
1N4148 | D8,D13,D18,D23,D27,D31,D4,D9,D14,D19,D24,D28,D32,D10,D15,D20,D25,D29,D33,D1,D6,D11,D16,D21,D26,D30,D34,D2,D7,D12,D17,D5,D22,D3 | D_SOD-123 | C81598
3A Resettable fuse, polymeric positive temperature coefficient, small symbol | F1 | Fuse_1206_3216Metric | C70085
1.5A Resettable fuse, polymeric positive temperature coefficient, small symbol | F2 | Fuse_1206_3216Metric | C70081
8MHz Four pin crystal, GND on pins 2 and 4, small symbol | HSE1 | Crystal_SMD_3225-4Pin_3.2x2.5mm | C403948
2N7002 0.115A Id, 60V Vds, N-Channel MOSFET, SOT-23 | Q1 | SOT-23 | C8545
AO3401A -0.18A Id, -60V Vds, P-Channel MOSFET, SOT-23 | Q3 | SOT-23 | C15127
10k | R1,R4,R2,R3,R24,R25,R11,R14 | SMD-0603 | C25804
0 | R13,R12,R6,R5 | SMD-0603 | C21189
2k2 | R17 | SMD-0603 | C4190
33 | R18,R19 | SMD-0603 | C23140
1k5 | R20,R8,R7 | SMD-0603 | C22843
220 | R21 | SMD-0603 | C22962
100k | R22,R27 | SMD-0603 | C25803
200k | R23 | SMD-0603 | C25811
5k1 | R9,R10,R26 | SMD-0603 | C23186
BL24C512A-SFRC I2C Serial EEPROM, 512Kb, DIP-8/SOIC-8/TSSOP-8/DFN-8 | U1 | TSSOP-8_4.4x3mm_P0.65mm | C169114
XC6206P332MR | U2 | SOT-23 | C5446
SRV0504 Very low capacitance ESD protection diode, 4 data-line, SOT-23-6 | U3,U4 | SOT-23-6 | C384888
STM32F303CCTx ARM Cortex-M4 MCU, 128KB flash, 32KB RAM, 72MHz, 2-3.6V, 37 GPIO, LQFP-48 | U5 | LQFP-48_7x7mm_P0.5mm | C81523
MD1621 Low-Voltage Rail-to-Rail Output Operational Amplifiers, SOT-23-5/SC-70-5 | U6 | SOT-23-5 | C126981

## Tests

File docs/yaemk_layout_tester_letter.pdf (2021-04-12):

# YAEMK Rev 1.2 Key Layout Tester

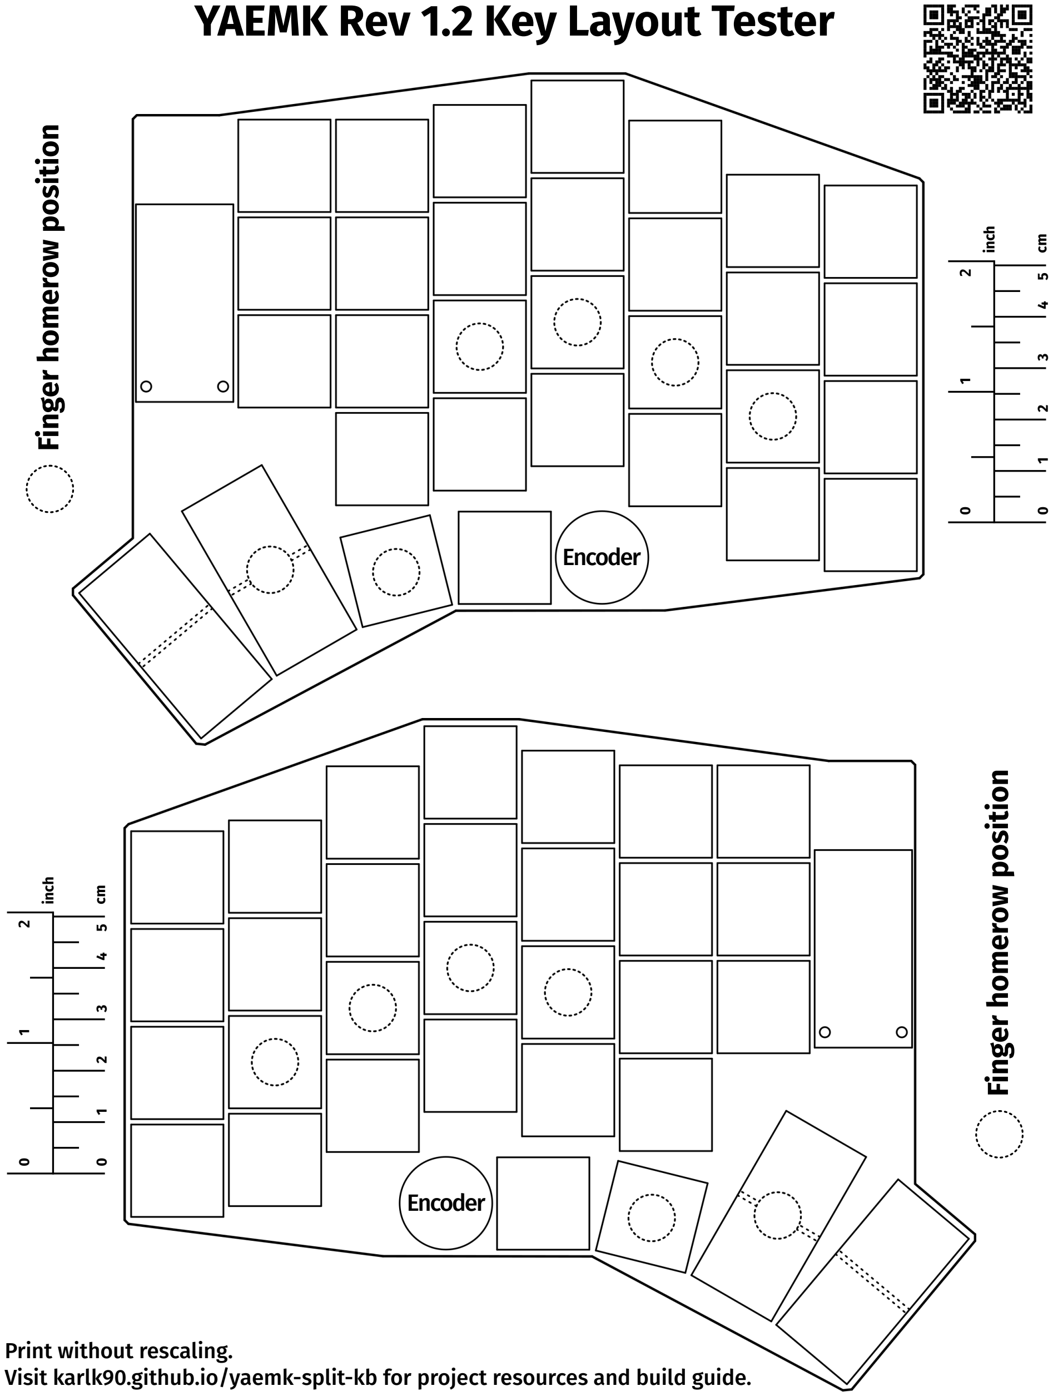
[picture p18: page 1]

Print without rescaling.
Visit karlk90.github.io/yaemk-split-kb for project resources and build guide.

Encoder

Encoder

## Finger homerow position

0 1 2
0 1 2 3 4 5

inch
cm

0 1 2
0 1 2 3 4 5

inch
cm

## Finger homerow position

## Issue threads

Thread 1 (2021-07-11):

Wireless?

Zwo1in, 2021-07-11:
Hi,
When I saw this layout, I've instantly felt it's my endgame :o however I also would like to go wireless with things like nice!nano. Is it possible that you'd make this possible? :)

KarlK90, 2021-09-07:
Thanks for the kind words! Sorry for the late response, I didnt see your issue earlier.

As the board uses an mcu directly soldered to the PCB this would need a complete redesign to fit the nrf52840 plus charging circuits, an antenna and a battery.

This is doable but the current layout and schematic is tightly coupled to the gd32vf103 or stm32f303 mcus. For a proper wireless build the rgb LEDs and OLEDs don't make much sense as they consume a lot of power. That is why a wireless version would use a very different design, which I just don't have the time for sorry.

The easiest way would be to fork this repo and replace the on-board mcu with a nicenano footprint or go all the way and do an on-board nrf52840.

Cringely, 2022-10-17:
Subscribing should @KarlK90's wants/needs ever motivate them to do such a redesign. Or any friendly stranger with the skillset to fork and do so.

Thanks :)

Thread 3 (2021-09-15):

Incorrect format in BOM file PCB/assembly/YAEMK_bom.csv

siu, 2021-09-15:
These days I tried to place an order in JLCPCB and the SMT process was failing with the message:

```
Incorrect format
No valid content found.
```

Support told me that the BOM file was missing a header, adding the following in the first line of `PCB/assembly/YAEMK_bom.csv` fixes the import:

`Comment,Designator,Footprint,JLCPCB Part`

Thanks again for sharing the YAEMK design and the great documentation.

KarlK90, 2021-09-15:
Corrected that, thanks!

Closed 2021-09-15.

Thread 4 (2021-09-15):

[question] Compatible component replacements?

siu, 2021-09-15:
I am trying to order the YAEMK from JLCPCB and currently three parts are out of stock:

- The microcontroller, this is already documented, I will source it from somewhere else
- ON Semiconductor CAT24C512YI-GT3 https://www.lcsc.com/product-detail/EEPROM_ON-Semiconductor-CAT24C512YI-GT3_C56096.html
- 3PEAK LMV321TP-TR https://www.lcsc.com/product-detail/Operational-Amplifier_3PEAK-LMV321TP-TR_C90297.html

I would like to replace these by other compatible parts, I found the two that follow but I don't have enough experience with electronics to know if these are really compatible:

- BL(Shanghai Belling) BL24C512A-SFRC (https://www.lcsc.com/product-detail/EEPROM_BL-Shanghai-Belling-BL24C512A-SFRC_C169114.html)
- Shanghai Mingda Microelectronics MD1621 (https://www.lcsc.com/product-detail/Operational-Amplifier_Shanghai-Mingda-Microelectronics-MD1621_C126981.html)

I would appreciate if you could confirm that these are compatible (or not).

KarlK90, 2021-09-15:
The EEPROM and OP-amps are pin-compatible and I'm very certain that they are functionally equivalent! If any of the components should fail there will be a workaround, as the plug detection can be disabled and the internal EEPROM emulation is now available for the GD32VF103.

KarlK90, 2021-09-15:
I have added an alternate BOM with those components and linked it in the build guide. Thank you.

siu, 2021-11-10:
Hi @KarlK90, I am happy to share that I ordered and built the keyboards, they work perfectly with the replacement components, yay! For the MCU I chose the RISC-V in the Longan Nano, desoldered and soldered it in the boards. The MCU and USB connectors are hard to solder but it is doable with decent tools and patience. I did not install any of the LED lights but I may add them in the future. Note that I have not tested the EEPROM yet as I don't have any real use for it, I may hack something together in the following days to check if it works.

For the programming, I was also able to set up the toolchain to build for RISC-V following the instructions, no issues at all.

The build guide is very well written and I was able to follow it even not having much experience in electronics, thanks for that!

The only thing I found confusing is the example firmware. At that stage in the build I think the interest is to check the wiring is correct.
 - I found that using the keyboard was very erratic, until I realized that it has home row modifiers. Understanding that I could check that all keys worked as expected (or not, see next point). If you agree I can upload a simpler keymap with the name "testing" to be used in the guide.
 - Keys 3 and 8 register the key below them randomly, for example tapping 3 would result in "3eee" written. I did not know if the wiring was wrong or it was a firmware issue. Anyway I continued with the programming of the board and it looks like the issue is already solved in your fork of the qmk_firmware (https://github.com/KarlK90/qmk_firmware/commit/dfb777e3d0764e0bd19d9e59b0e39b02f7c8b479 at the time of writing). Just recompiling fixed it.

I also hear the coil whine when the displays show some specific information as you reported in https://github.com/qmk/qmk_firmware/pull/10379#issuecomment-819630957.

Again, thanks for sharing the project, it is a lot of fun.

KarlK90, 2021-11-10:
Hi @siu that is great news, happy that you have a working YAEMK now :muscle:!

>     * I found that using the keyboard was very erratic, until I realized that it has home row modifiers. Understanding that I could check that all keys worked as expected (or not, see next point). If you agree I can upload a simpler keymap with the name "testing" to be used in the guide.

You are right about the test firmware, I'll add a testing keymap and compile it as the default without homerow modifiers.

>     * Keys 3 and 8 register the key below them randomly, for example tapping 3 would result in "3eee" written. I did not know if the wiring was wrong or it was a firmware issue. Anyway I continued with the programming of the board and it looks like the issue is already solved in your fork of the qmk_firmware ([KarlK90/qmk_firmware@dfb777e](https://github.com/KarlK90/qmk_firmware/commit/dfb777e3d0764e0bd19d9e59b0e39b02f7c8b479) at the time of writing). Just recompiling fixed it.

This is actually caused by EMI noise of the matrix lines, because the matrix scanning is rather fast on this board. To fix the issue the output pins have been assigned the slowest possible speed (which is plenty fast for this simple use-case). You can see the corresponding lines in this [commit](https://github.com/KarlK90/qmk_firmware/blob/1aced62939e4a31f283923dad6e90a948c545a1b/keyboards/karlk90/yaemk/yaemk.c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).

> I also hear the coil whine when the displays show some specific information as you reported in [qmk/qmk_firmware#10379 (comment)](https://github.com/qmk/qmk_firmware/pull/10379#issuecomment-819630957).

Yes, these oleds are a bit on the cheap side. I already got some burn-in after one year but nothing to bad. Maybe the whine could be reduced further by swapping the coils on the board but it is not that bad I recon.

> Again, thanks for sharing the project, it is a lot of fun.

Thanks for the kind words. :muscle::slightly_smiling_face:, wish you lots of fun with your YAEMK!

siu, 2022-02-05:
I confirm that the replacement EEPROM works as expected, I am using it now to store the default layer between two different configurations I am experimenting with.

Closing the issue as well as the questions were already answered :)

KarlK90, 2022-02-06:
> I confirm that the replacement EEPROM works as expected, I am using it now to store the default layer between two different configurations I am experimenting with.
>
> Closing the issue as well as the questions were already answered :)

Great to hear that you apparently use your YAEMK. I Don't if you already did that but, if you want share you build on Reddit. 🙂

Closed 2022-02-05.

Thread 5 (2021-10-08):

Open Know-How sample project?

hoijui, 2021-10-08:
Hey Karl! :-)
We are a group of Open Hardware enthusiasts from germany (mostly Berlin), who are trying to improve the state of Open Source Hardware (OSH), and we have some projects going that deal with standardization and meta-data, where we would be interested in having your project as one of the examples if you are interested.
We already have the [corne](https://github.com/foostan/crkbd/) covered (which I am sure you know), but as yours allows to use a RISC-V chip, we are of course extra thrilled! :-)
We have some requirements for the repo for this, with which we could also help, If you need it. First you would have to decide if thee changes are ok for you, of course.

KarlK90, 2021-11-11:
Hi @hoijui just as a heads up, I have started adding the required metadata to the project and will continue on this in the upcoming days.

hoijui, 2021-11-11:
WOO HOO! :D
ehhh super Karl! :-)
das freut mich sehr zu hoeren! :-)
ich hab vor 10 tagne oder so, ein angebot gekriegt vo neiner firma in hong kong, dass sie mich gerne untersteutzten wuerden, wegen eines meiner projekte (den <https://github.com/hoijui/kicad-text-injector>), und ihc bin nohc immer verbluefft.. weis nciht genau wie.. also die weurden wahrscheinlich... mindestens boards spendieren. also wenn du fuer sowas auhc offen bist, das auszuprobieren... koennten wir das auch mit deiner tastatur dann machen, wenn du fertig bist.
und wer weiss, vielleicht haben die ja noch paar risc-v prozessoren fuer uns auf lager .. ;-)

... ein freund ihc auhc interessiert an einer split-tastatur, schaut aber noch herum (weiss nicht was so sein ding ist).
und sag gern beschied wenn du hilfe brauchst/willst, bei etwas.
danke fuer den heads-up!

hoijui, 2021-11-16:
Just now saw that you already uploaded it to the repo when you last wrote. ;-)
thank you!

I added a progress indicator to [the first post of this issue](https://github.com/KarlK90/yaemk-split-kb/issues/5#issue-1020739322). All the leftover stuff, I would take as my responsibility, if you are not eager to do it yourself, and if you are willing to accept it into your repo, once it's done.

I would copy over most of it from the [for-science-keyboard](https://github.com/hoijui/for-science-keyboard/tree/oseg) (Note: branch `oseg`, not `master`), though with reduced complexity.

hoijui, 2021-11-16:
@KarlK90 , how did you design the case?
as in: with what process/software; Are the SVGs the source files or generated?

hoijui, 2021-11-16:
Regarding all the content files (mainly images and Markdown): would you like to use CC-BY-SA-4.0 for those, or also GPL?
I like GPL, but it is meant for code only, so I tend to plit it up like this.
I am asking, so I can start adding license info on a per-file granularity,
for [REUSE](https://reuse.software/) compliance.

KarlK90, 2021-11-16:
@hoijui Thanks for providing your help and sure go ahead.

I'll answer in more detail this evening. For the content files use CC-BY-SA-4.0.

The case files are generated from the PCB, altough that if 50/50 manual work. If you check the user defined layers on the switch footprints you can see drawings for 0mm kerf and 0.1mm kerf. I exported these layers and edge.cuts to SVG and manually deleted/modified them. That is a but cumbersome but worked quite nicek

KarlK90, 2021-11-17:
> WOO HOO! :D ehhh super Karl! :-) das freut mich sehr zu hoeren! :-) ich hab vor 10 tagne oder so, ein angebot gekriegt vo neiner firma in hong kong...

Sehr cool, kann verstehen das du da richtig verblüfft bist :slightly_smiling_face:. Das PCB Angebot klingt super, ich bin bisher noch gut versorgt aber falls sich dein Bekannter für YAEMK entscheidet wäre das eine interessante Idee. :+1: Ich habe hier auch noch mindestens 6 GD32VF103 rumfliegen davon kann ich bei Bedarf auch noch welche abzwacken.

KarlK90, 2021-11-17:
>     * all generated files (firmware binaries, gerber files, ...) should not be in the repo, but rather be generated automatically for each commit (or alternatively each release). They could be uploaded as github action artifacts or (preferably), hosted on the projects pages, which you are already using. :-)

I like the idea to auto-generate all the artifacts for this project, although the development of the YAEMK is basically finished at this point (time to do a proper release with a tag). So my only concern with this approach is that generating all the artifacts manually takes me about 30min. Setting up CI and process would take longer I recon and would not have a time saving factor as there will not be many releases in the future. The main benefit would be a nicely working example for the community on how to do it.

>     * include meta-data onto the PCB (using text and/or QR-Code)

That sounds neat! There is a bit of space left on back of the PCBs right next to the split comms usb-c port that could be used for that.

hoijui, 2021-11-22:
> The main benefit would be a nicely working example for the community on how to do it.

YES! :-)
the project I linked to (for-sicence-keyboard) is one I put a lot of time into, even though I knew I will probably never want to produce it physically. Still, to copy things over from there to this project, will save a lot of time, and it will already allow to make the thing be more generic, so it will fit more easily to more general projects.
I can not say when yet, but I'll have a go at it (as it will probably also be easier for me, already knowing all the parts of the auto-generation).
.. one thing maybe: could you try to compile the firmware on CI? or maybe someone already does that (given it is qmk, I imagine that is quite likely, right?)

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

NICE! thanks! :-)
... just now reading this, I though...
so the way the image injection utility works, is that one manually adds a rectangle on the PCB (most likely on the silk layer, potentially on the copper layer) in KiCad, which later gets replaced by the image (e.g. the QR-code) in CI. If one were to use the source KiCad PCB directly, and not use the same process as in CI (even though it will be available through a script that one can also run locally), one would end up with a rectangle in that place on the PCB, if it is not removed. I personally to not see this as a problem.. in the worst case, one would shortly wonder what this is supposed to mean, and go on with it. It is something to consider, though. Also, if you have an idea how to circumvent this nicely, feel free to tell. Maybe there is an other way to indicate placeholders on the board? (what I need in the end, is just location and size), or one could add additional text that indicates the placeholder as such, or use only text as placeholder, with the text starting with a custom prefix, ...
We could theoretically also mix those approaches, though it might then get confusing for the users. after all, it is supposed to be a simple CLI tool. but yeah.. am open to suggestions.

> Thanks for your effort and dedication in promoting my project, I really appreciate it.

Thank you for your collaboration too! :-)

hoijui, 2021-12-21:
Soo... finally had a little bit of attention left to spend today.
I know that @cryptix is working on something on this list as well ... not spoiling anything yet! ;-)
... things are moving!

KarlK90, 2021-12-21:
@hoijui Thanks for the heads-up and looking forward to what @cryptix is cooking :wink:

hoijui, 2022-02-17:
work on the QR code integration is still in progress.. not forgotten!
@cryptix already did his part (a Docker image with the required tools), now it's my turn for integrating it for testing (side project), then we'll try it here too.

KarlK90, 2022-03-05:
> our crawler found your project, and you are now enlisted! :-) https://losh.opennext.eu/detail/Q3762 This does not really give any real world benefit now, but we will continue to use this standard and the crawled data, and .. well.. at least in some way, you are now a bit more findable, already. :-)

Yeah, very cool! I got the email as well :-) Thanks for the continued effort!

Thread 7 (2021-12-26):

Different reset behaviour

toniz4, 2021-12-26:
When reading the guide i noticed that the way of enabling the bootloader mode in the arm chip is different from the risc v chip, why so?

KarlK90, 2021-12-30:
The GigaDevice circuitry inside the GD32VF103 is different enough from the STM32F303 that the combined Reset and BOOT0 pin triggering circuit that is operated by the DFU button doesn't work properly. So the plug / unplug procedure is needed as a workaround.

toniz4, 2021-12-30:
Got it, thanks!

Closed 2021-12-30.

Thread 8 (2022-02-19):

Choc switches

wren, 2022-02-19:
Hi! I just wanted to say that I absolutely love your design!

Is there any chance that you would be willing to add support for low profile (i.e. choc) switches? I think that's the only thing that's missing to make this the perfect board for me.

KarlK90, 2022-03-05:
@wren Thanks for the kind words! :slightly_smiling_face:

Unfortunately choc switches are not easily compatible with the overall design, and require extensive rework of the switch matrix of the pcb and the top plates. And my time is rather scarce in the future so I don't have any plans to do that change...

wren, 2022-03-05:
> @wren Thanks for the kind words! :slightly_smiling_face:
>
> Unfortunately choc switches are not easily compatible with the overall design, and require extensive rework of the switch matrix of the pcb and the top plates. And my time is rather scarce in the future so I don't have any plans to do that change...

Ok, that's completely understandable. Thank you for the reply, anyway!

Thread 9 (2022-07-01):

Doubt on JP1 and JP2 soldering

dnbias, 2022-07-01:
Hi, thank you for the awesome work on this keyboard!

Thinking about building this I was reading through your step-by-step instructions and step 4. is not very clear to me.
You refer to JP1 and JP2 although I didn't find them on the interactive BOM and I'm not sure what you mean by
"connect the left pad with the middle pad on both jumpers via a solder bridge on the left side of the keyboard", and then mirrored on the right side. Left pad here is left in relation to what?
I'm sorry if it's obvious but I'm new to these things :smile:

Visne, 2022-07-02:
They are not on the BOM as they are not physical items, you just connect two pads on the PCB with solder (a solder bridge).

The two halves of the keyboard connect with each other via a cable. Both halves have an RX (receive) line and a TX (transmit) line. If you would solder both PCBs the exact same, you would end up soldering the RX of the left half to the RX of the right half, and the same for TX. This doesn't make sense, as you want the transmitting end from the left half to end up at the receiving end of the right half, and vice versa. Therefore, you have to solder both sides slightly differently.

Now, I don't fully understand "right and left pads" either, it makes more sense to call them top and bottom pads I think. If you look at the [finished left handed PCB](https://karlk90.github.io/yaemk-split-kb/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) you can see what's going on:

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

Here, the two middle pads are connected to the two bottom pads.

On the right handed side of the keyboard, you would instead solder the two middle pads to the two top pads. Then, RX is connected to TX and TX is connected to RX.

dnbias, 2022-07-02:
Thank you, that makes much more sense! I imagined it was something like that but thought I'd ask anyway.

Closing.

Closed 2022-07-02.

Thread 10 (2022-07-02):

KiCad plot options

Visne, 2022-07-02:
Thanks for this nice layout and the awesome documentation.

I'm trying to remove the logo from the silkscreen (I think I would like the 'clean' look), but I'm not sure how I should plot the gerber/drill files.

For refernce, these are the defaults for gerbers:

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

And for drill files:

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

Thanks!

Visne, 2022-07-02:
Also, this is asked when plotting:

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

I assume I should just click Refill, but better to be sure.

Visne, 2022-07-02:
The [JLCPCB support page](https://support.jlcpcb.com/article/194-how-to-generate-gerber-and-drill-files-in-kicad-6) seems to be quite clear on what option are required, however with the current .kicad_pcb file I seem to have no F_Paste layer.

KarlK90, 2022-07-07:
> Thanks for this nice layout and the awesome documentation.

@Visne Thank you! Somehow I didn't got your message as a notification. The paste layer is not necessary, it will be derived from the solder mask layer. Please check your drill settings, you selected inches instead of millimeters.

Visne, 2022-07-07:
@KarlK90 Thanks, then I will order them soon!

Closed 2022-07-07.

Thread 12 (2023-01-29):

Case SVG creation method

TheZoq2, 2023-01-29:
Hi! Thanks for making this amazing and well documented keyboard. I had some extra requirements, so I ended up adding another 2 switches, and moving 2 of the columns a bit.

However, this means the case won't fit, so I'm curious if you have some method for generating the case svg from kicad, or if you just did it by hand.

KarlK90, 2023-03-03:
@TheZoq2 Thanks for the kind words! I've actually played around quite a bit with the stm32 rust hal crates, so I can give my thanks right back. To your question the SVGs for the cases are directly exported from the KiCAD files, the user layers (I don't recall the exact name) have the cutouts for the switches in 0.1mm kerf and without kerf. For completeness you also need the edge cuts layer. Then it is just a matter of keeping the right elements in the exported svg.

TheZoq2, 2023-03-03:
Nice, that sounds simple enough, thanks!

Also, perhaps you'd be interested to know that I run rust on my yaemk https://gitlab.com/TheZoq2/yayaemk :)

KarlK90, 2023-03-03:
Nice, I hope you enjoy your yayaemk!

Closed 2023-03-03.

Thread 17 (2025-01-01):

JLCPCB SMT Assembly: "below parts won't be assembled due to data missing" -> OK?

hoijui, 2025-01-01:
When trying to order the PCB with SMT assembly from JLCPCB right now, I got this warning/error:

> The below parts won't be assembled due to data missing.
P1,P2,G1,D70 designators don't exist in the BOM file.

I imagine that is fine/expected, but wanted to ask anyway.
(I will not order right now anyway, just wanted to see how the process goes and to have an idea about the price)

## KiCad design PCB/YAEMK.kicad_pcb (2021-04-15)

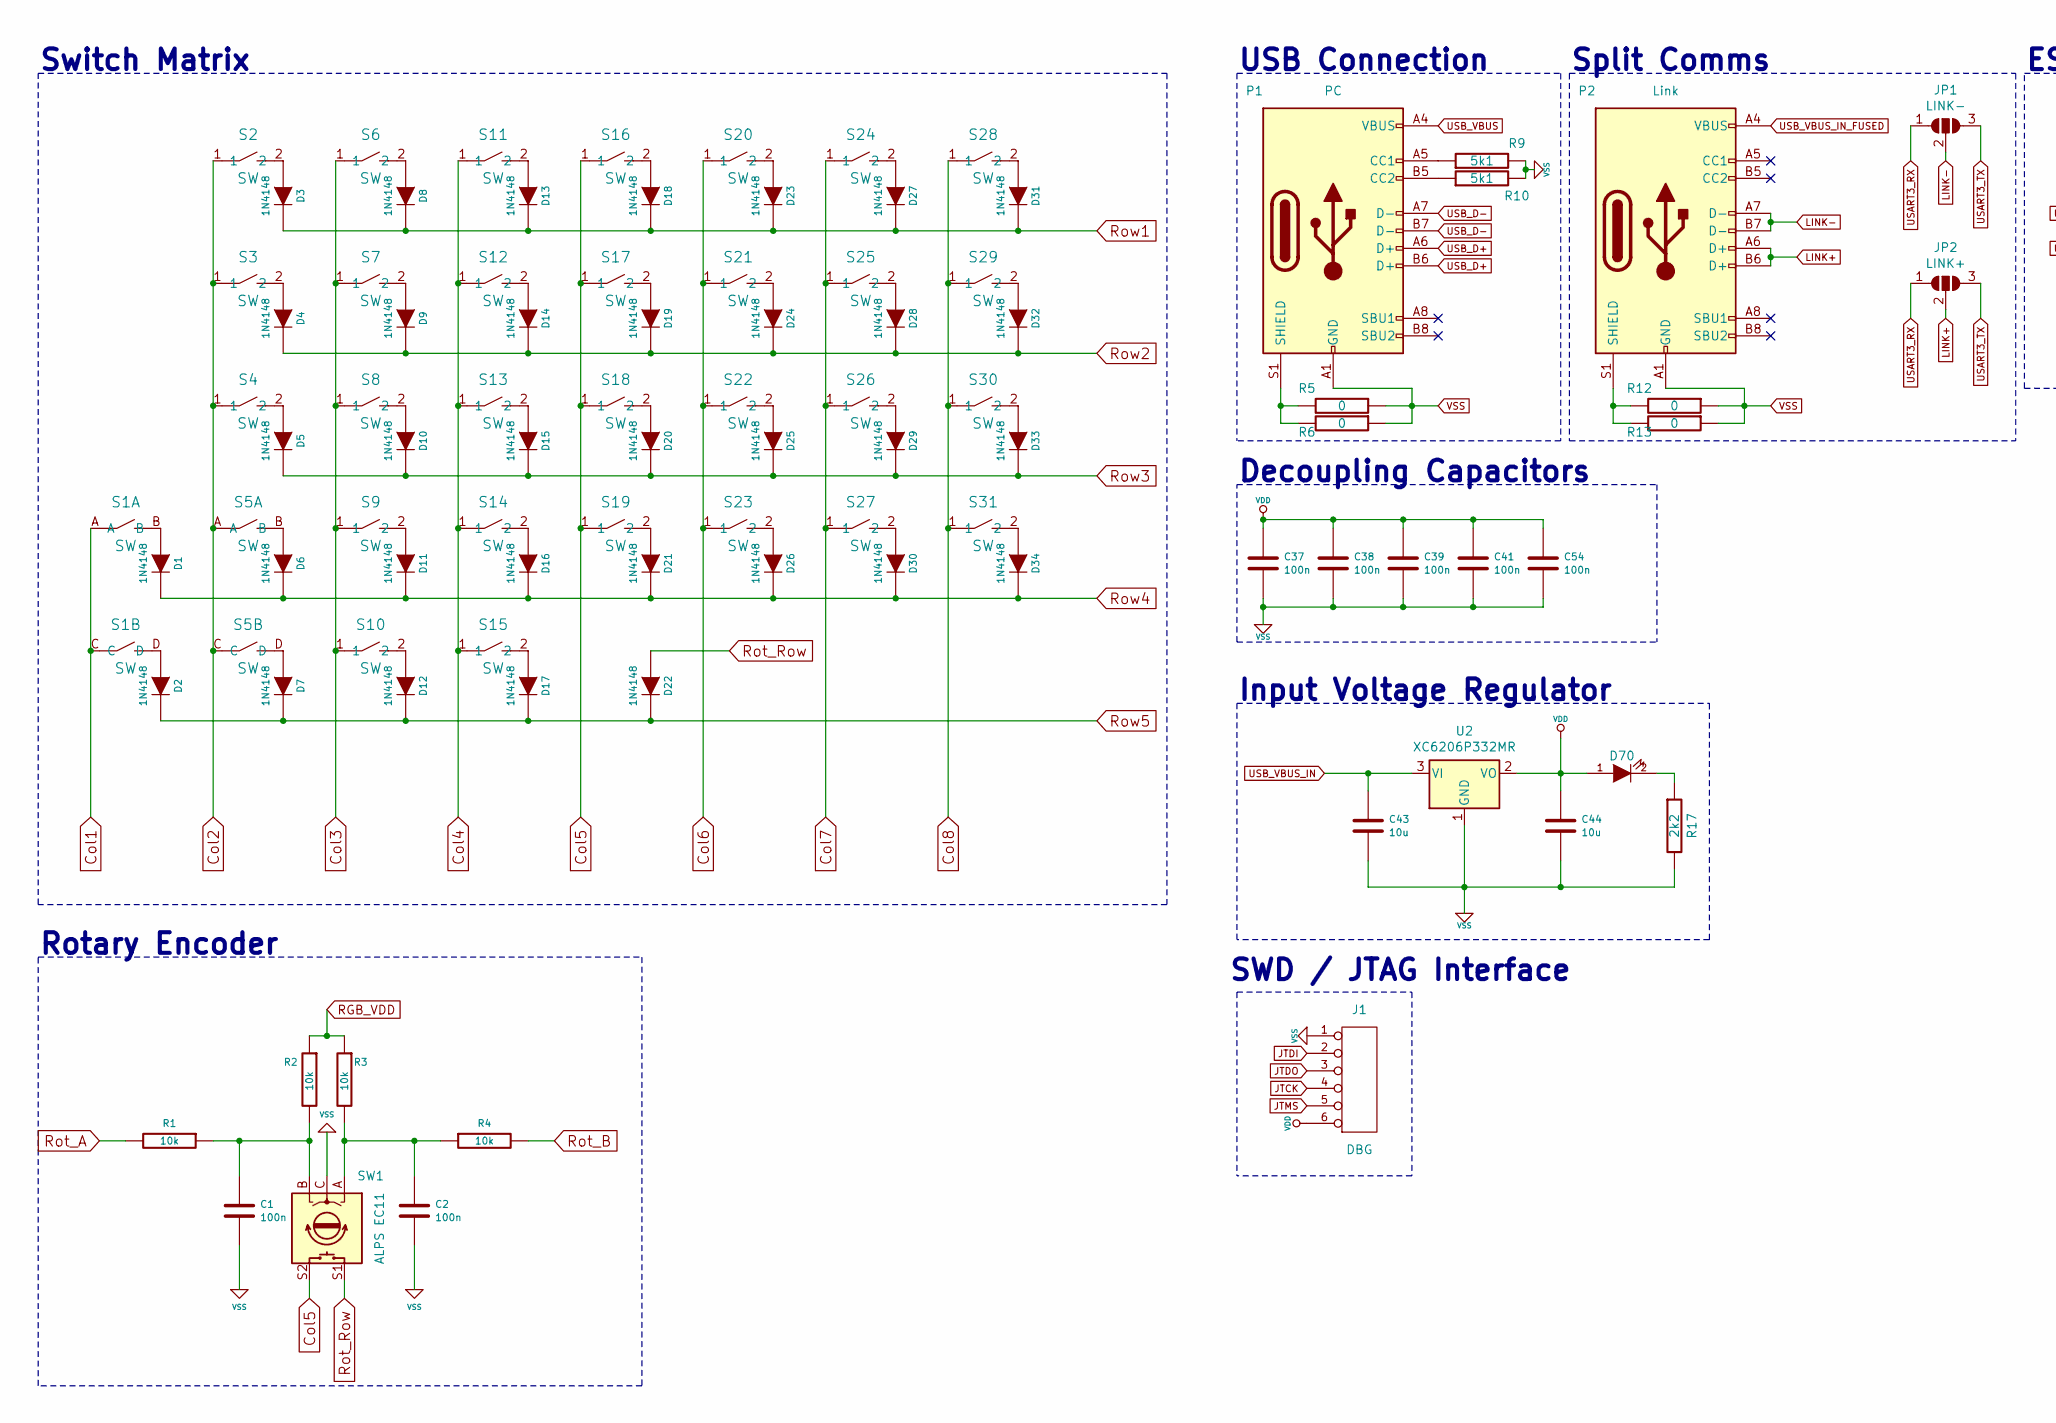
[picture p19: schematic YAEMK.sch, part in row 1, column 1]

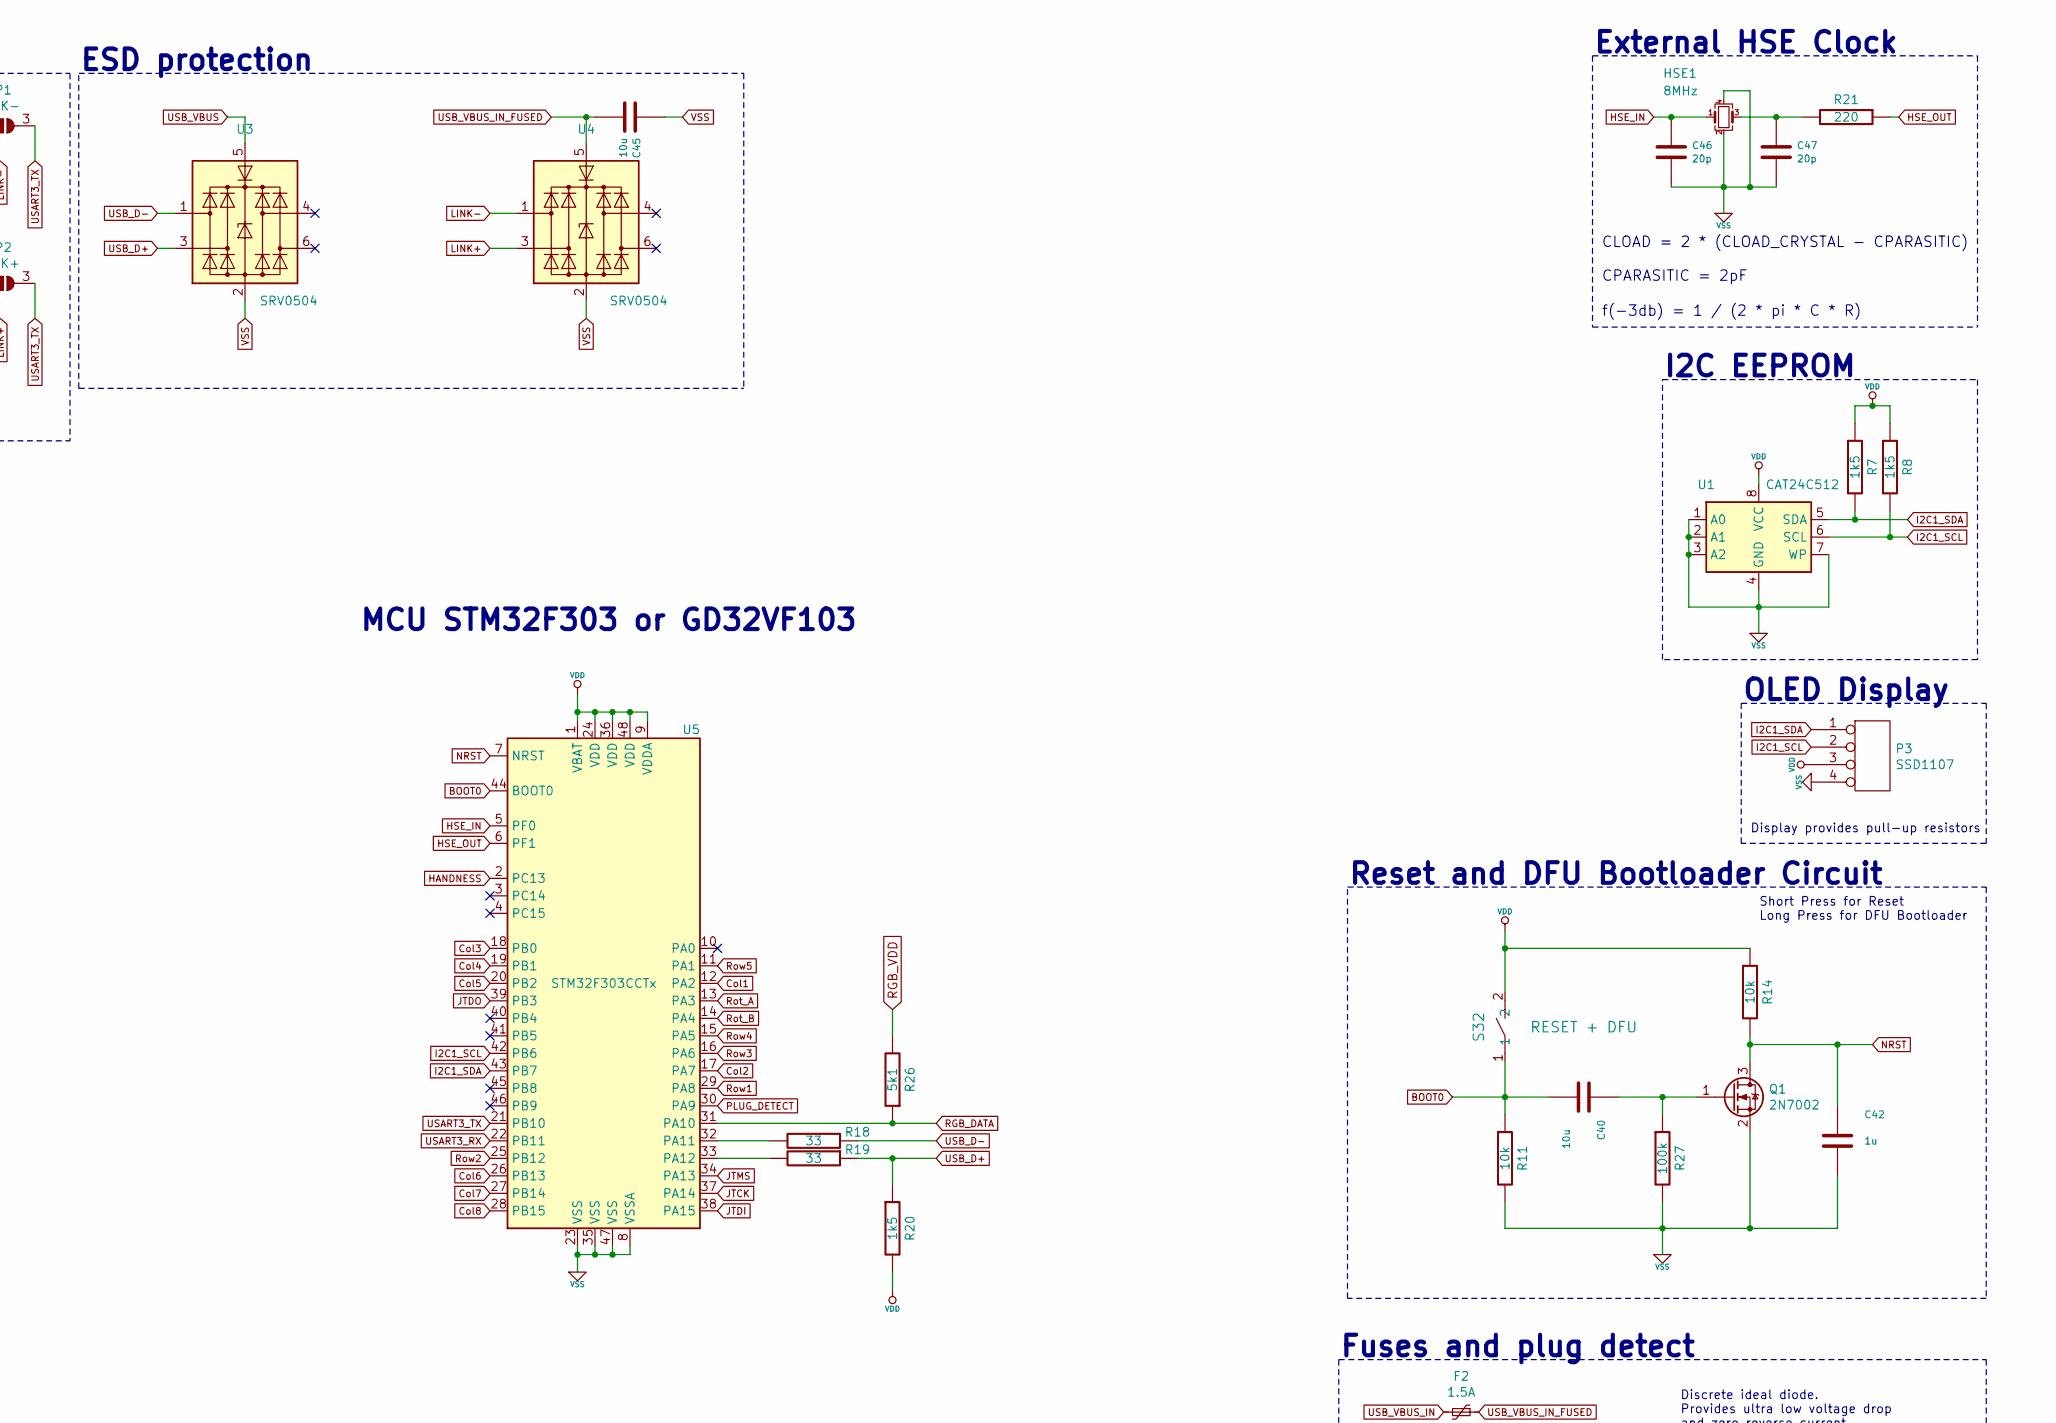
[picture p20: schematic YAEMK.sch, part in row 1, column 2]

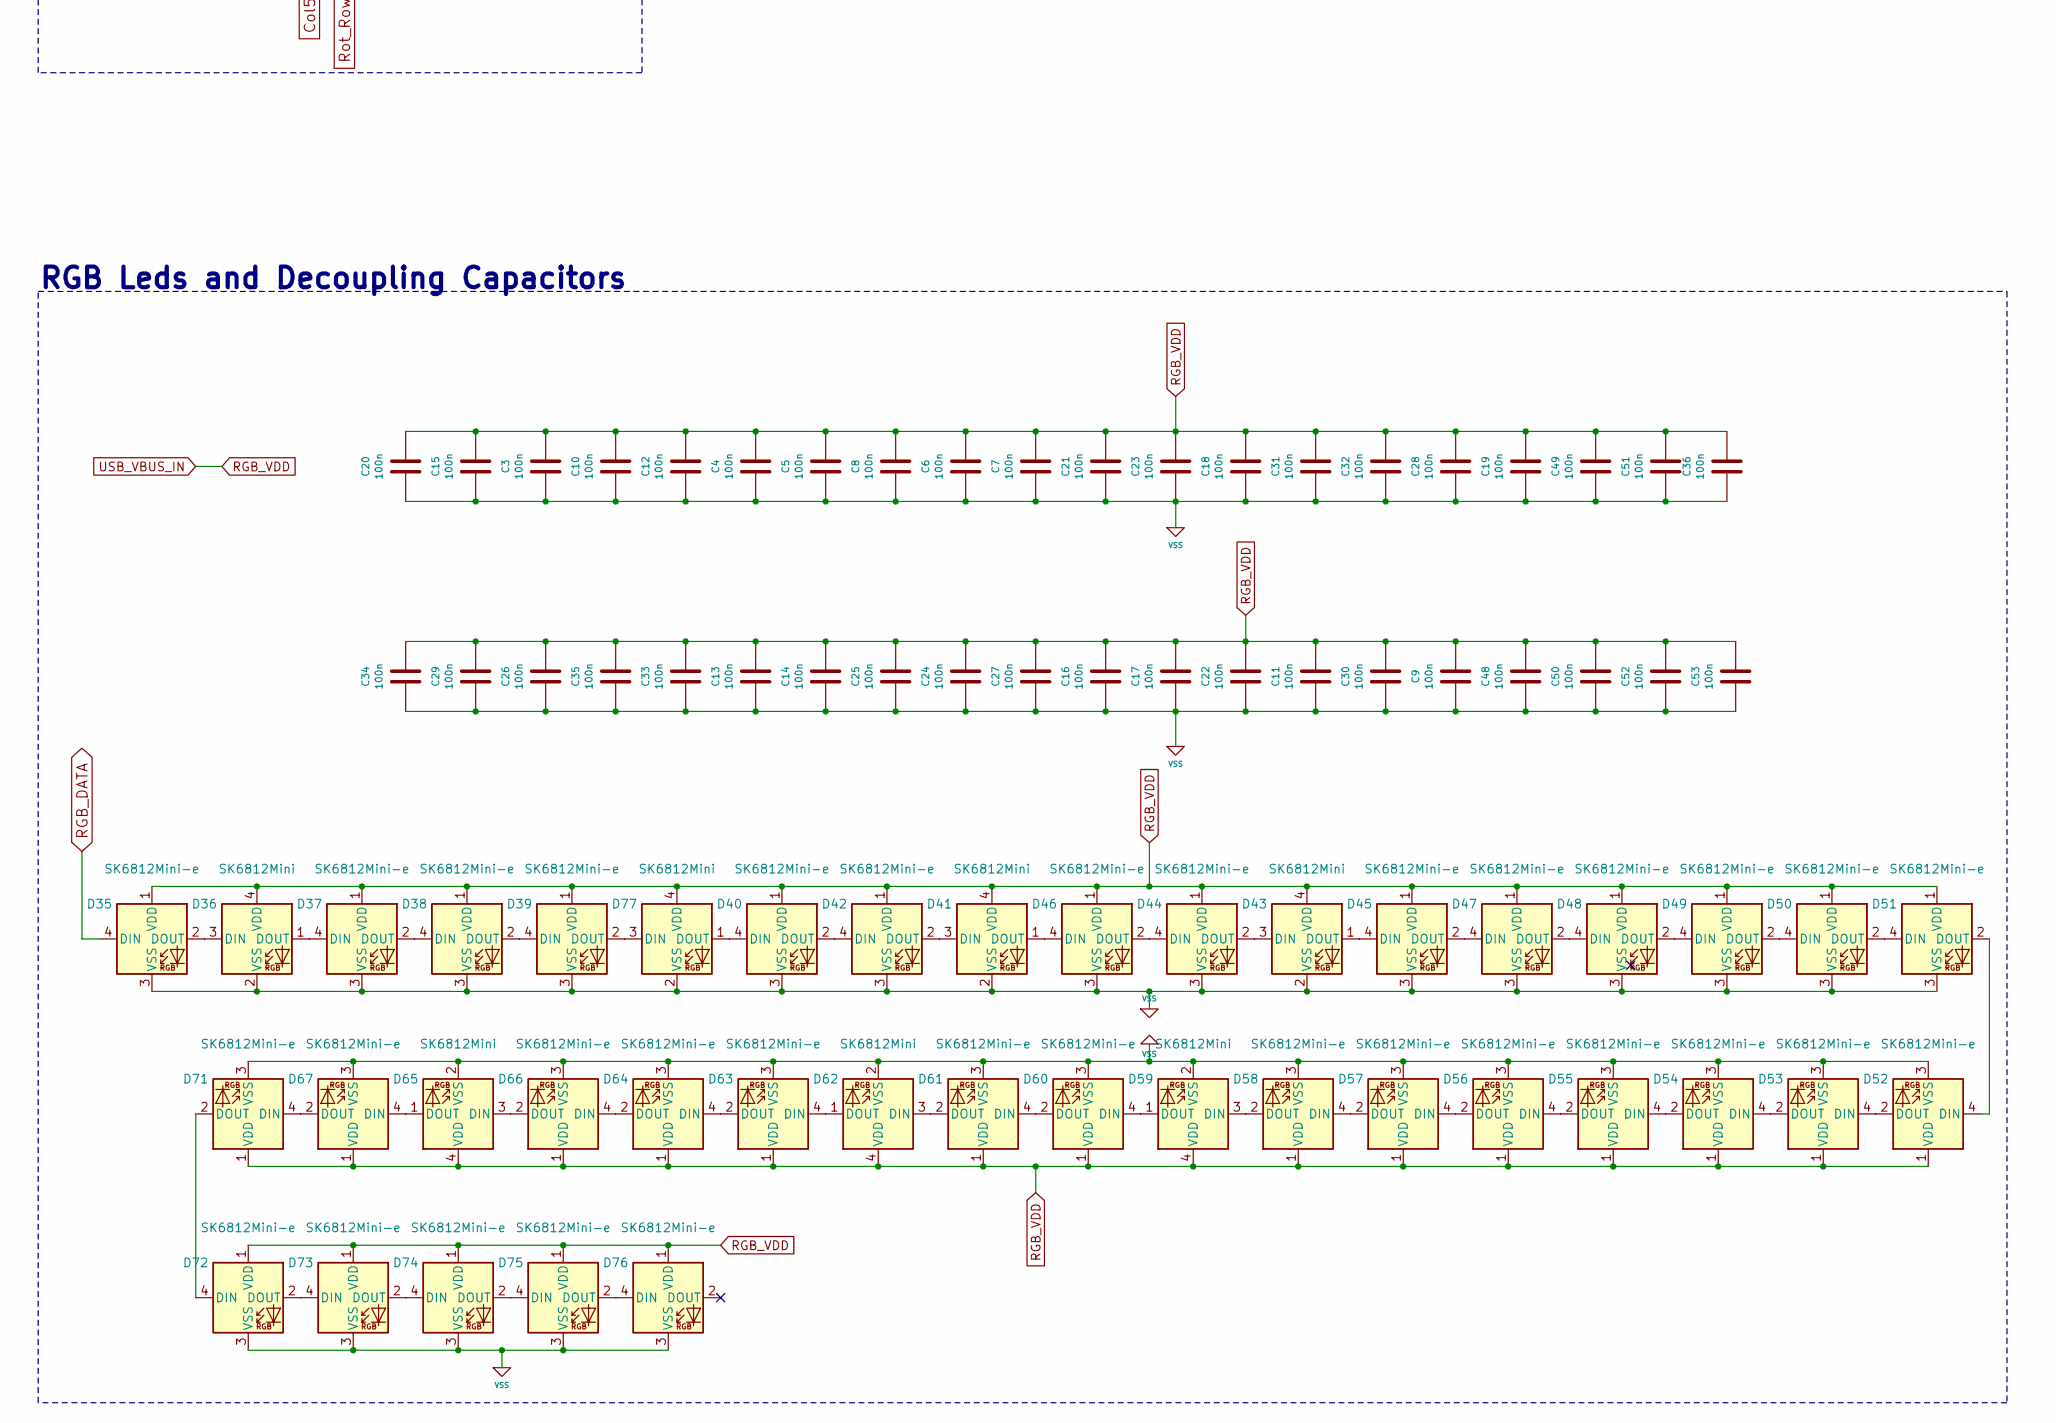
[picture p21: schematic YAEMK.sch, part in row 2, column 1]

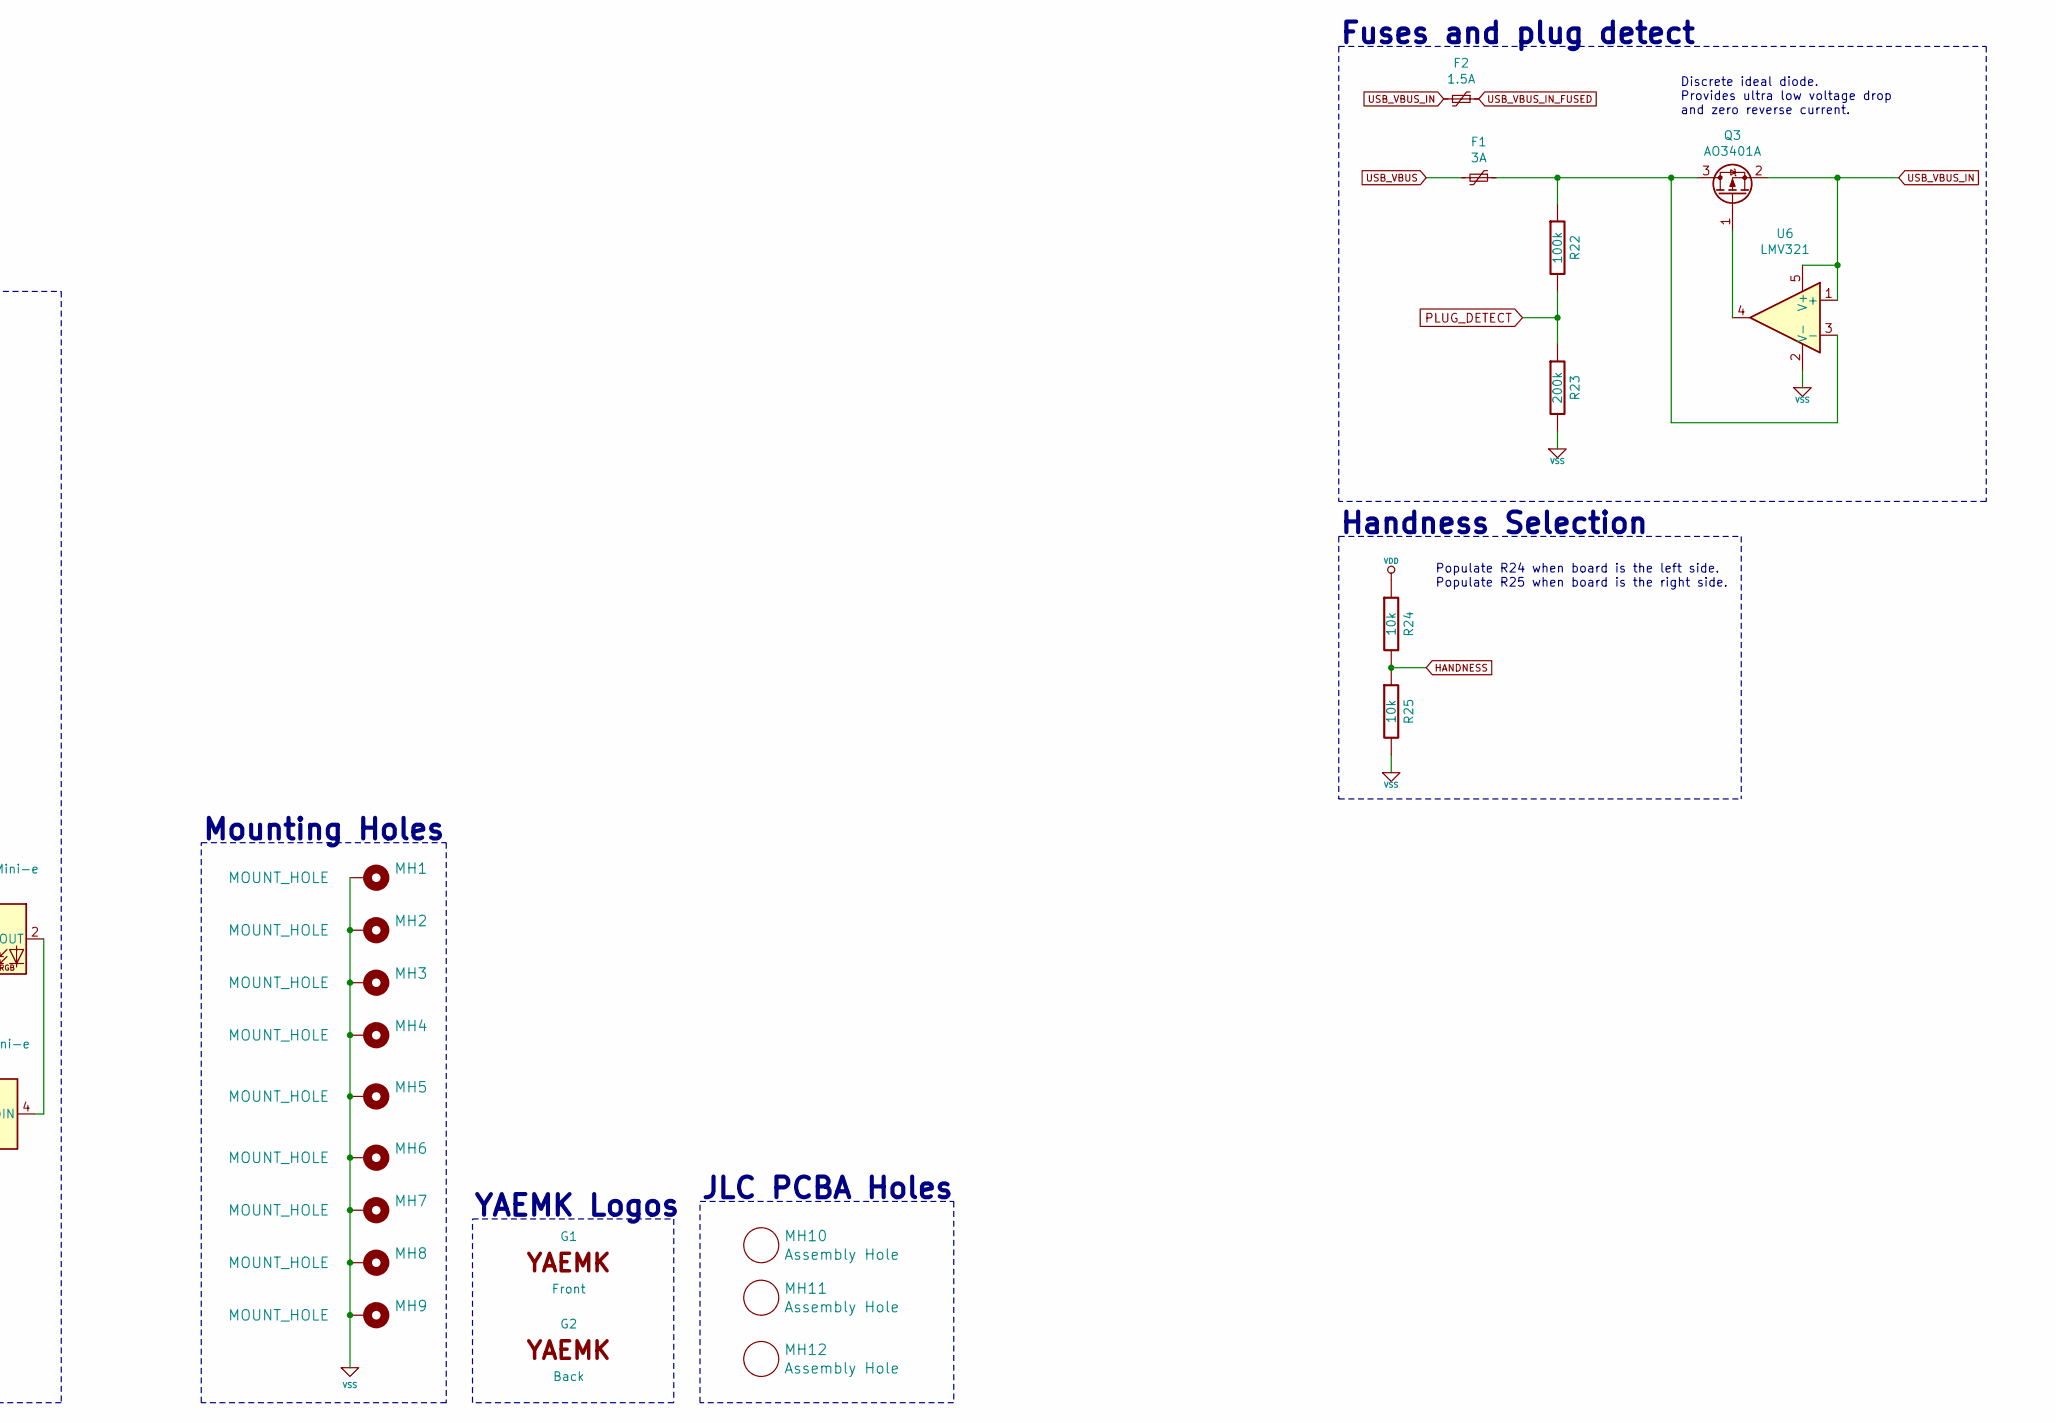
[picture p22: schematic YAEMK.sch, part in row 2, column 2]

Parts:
C1, C2, C3, C4, C5, C6, C7, C8, C9, C10, C11, C12, C13, C14, C15, C16, C17, C18, C19, C20, C21, C22, C23, C24, C25, C26, C27, C28, C29, C30, C31, C32, C33, C34, C35, C36, C37, C38, C39, C41, C48, C49, C50, C51, C52, C53, C54: 100n; SMD-0603; LCSC Part C14663
C40, C43, C44, C45: 10u; SMD-0603; LCSC Part C19702
C42: 1u; SMD-0603; LCSC Part C15849
C46, C47: 20p; SMD-0603; LCSC Part C1648
D1, D2, D3, D4, D5, D6, D7, D8, D9, D10, D11, D12, D13, D14, D15, D16, D17, D18, D19, D20, D21, D22, D23, D24, D25, D26, D27, D28, D29, D30, D31, D32, D33, D34: 1N4148; D_SOD-123; LCSC Part C81598
D35, D37, D38, D39, D40, D42, D44, D45, D46, D47, D48, D49, D50, D51, D52, D53, D54, D55, D56, D57, D58, D60, D61, D63, D64, D66, D67, D71, D72, D73, D74, D75, D76: SK6812Mini-e; SK6812_mini_e_flipable; JLCPCB BOM 0
D36, D41, D43, D59, D62, D65, D77: SK6812Mini; SK6812_mini_flipable; JLCPCB BOM 0
D70: LED; LED-0603_flipable; LCSC Part C268294
F1: 3A; Fuse_1206_3216Metric; LCSC Part C70085
F2: 1.5A; Fuse_1206_3216Metric; LCSC Part C70081
G1: Front; LOGO; JLCPCB BOM 0
G2: Back; LOGO; JLCPCB BOM 0
HSE1: 8MHz; Crystal_SMD_3225-4Pin_3.2x2.5mm; LCSC Part C403948
J1: DBG; PinHeader_1x06_P2.54mm_Horizontal; LCSC Part C376124
JP1: LINK-; SOLDER_JUMPER_3; JLCPCB BOM 0
JP2: LINK+; SOLDER_JUMPER_3; JLCPCB BOM 0
MH1, MH2, MH3, MH4, MH5, MH6, MH7, MH8, MH9: MOUNT_HOLE; MountingHole_2.2mm_M2_Pad_Via; JLCPCB BOM 0
MH10, MH11, MH12: Assembly Hole; JLC_SMT_Assembly_Hole; JLCPCB BOM 0
P1: PC; USB_C_Receptacle_MUP_U22401; LCSC Part C168688
P2: Link; USB_C_Receptacle_MUP_U22401; LCSC Part C168688
P3: SSD1107; SSD1107_DISPLAY; LCSC Part C358718
Q1: 2N7002; SOT-23; LCSC Part C8545
Q3: AO3401A; SOT-23; LCSC Part C15127
R1, R2, R3, R4, R11, R14, R24, R25: 10k; SMD-0603; LCSC Part C25804
R5, R6, R12, R13: 0; SMD-0603; LCSC Part C21189
R7, R8, R20: 1k5; SMD-0603; LCSC Part C22843
R9, R10, R26: 5k1; SMD-0603; LCSC Part C23186
R17: 2k2; SMD-0603; LCSC Part C4190
R18, R19: 33; SMD-0603; LCSC Part C23140
R21: 220; SMD-0603; LCSC Part C22962
R22, R27: 100k; SMD-0603; LCSC Part C25803
R23: 200k; SMD-0603; LCSC Part C25811
S1, S5: SW; MX_KAILH_SOCKET_2U_2X1U; JLCPCB BOM 0
S2, S3, S4, S6, S7, S8, S9, S10, S11, S12, S13, S14, S15, S16, S17, S18, S19, S20, S21, S22, S23, S24, S25, S26, S27, S28, S29, S30, S31: SW; MX_KAILH_SOCKET_1U; JLCPCB BOM 0
S32: RESET + DFU; SMD_Tacticle_Switch_TS24CA_flipable; LCSC Part C393942
SW1: ALPS EC11; RotaryEncoder_Alps_EC11E-Switch_Vertical_H20mm; LCSC Part C370986
U1: CAT24C512; TSSOP-8_4.4x3mm_P0.65mm; LCSC Part C56096
U2: XC6206P332MR; SOT-23; LCSC Part C5446
U3, U4: SRV0504; SOT-23-6; JLCPCB BOM 1
U5: STM32F303CCTx; LQFP-48_7x7mm_P0.5mm; LCSC Part C81523
U6: LMV321; SOT-23-5; JLCPCB BOM 1

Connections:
BOOT0: C40.1, R11.1, S32.1, U5.44 (BOOT0)
Col1: S1.A, S1.C, U5.12 (PA2)
Col2: S2.1, S3.1, S4.1, S5.A, S5.C, U5.17 (PA7)
Col3: S6.1, S7.1, S8.1, S9.1, S10.1, U5.18 (PB0)
Col4: S11.1, S12.1, S13.1, S14.1, S15.1, U5.19 (PB1)
Col5: S16.1, S17.1, S18.1, S19.1, SW1.S2, U5.20 (PB2)
Col6: S20.1, S21.1, S22.1, S23.1, U5.26 (PB13)
Col7: S24.1, S25.1, S26.1, S27.1, U5.27 (PB14)
Col8: S28.1, S29.1, S30.1, S31.1, U5.28 (PB15)
HANDNESS: R24.2, R25.1, U5.2 (PC13)
HSE_IN: C46.1, HSE1.1, U5.5 (PF0)
HSE_OUT: R21.1, U5.6 (PF1)
I2C1_SCL: P3.2, R8.2, U1.6 (SCL), U5.42 (PB6)
I2C1_SDA: P3.1, R7.2, U1.5 (SDA), U5.43 (PB7)
JTCK: J1.4, U5.37 (PA14)
JTDI: J1.2, U5.38 (PA15)
JTDO: J1.3, U5.39 (PB3)
JTMS: J1.5, U5.34 (PA13)
LINK+: JP2.2 (C), P2.A6 (D+), P2.B6 (D+), U4.3 (I/O2)
LINK-: JP1.2 (C), P2.A7 (D-), P2.B7 (D-), U4.1 (I/O1)
NRST: C42.1, Q1.3 (D), R14.2, U5.7 (NRST)
unnamed: C1.1, R1.1, R2.2, SW1.B
unnamed: C2.1, R3.2, R4.1, SW1.A
unnamed: C40.2, Q1.1 (G), R27.1
unnamed: C47.1, HSE1.3, R21.2
unnamed: D1.2 (A), S1.B
unnamed: D2.2 (A), S1.D
unnamed: D3.2 (A), S2.2
unnamed: D4.2 (A), S3.2
unnamed: D5.2 (A), S4.2
unnamed: D6.2 (A), S5.B
unnamed: D7.2 (A), S5.D
unnamed: D8.2 (A), S6.2
unnamed: D9.2 (A), S7.2
unnamed: D10.2 (A), S8.2
unnamed: D11.2 (A), S9.2
unnamed: D12.2 (A), S10.2
unnamed: D13.2 (A), S11.2
unnamed: D14.2 (A), S12.2
unnamed: D15.2 (A), S13.2
unnamed: D16.2 (A), S14.2
unnamed: D17.2 (A), S15.2
unnamed: D18.2 (A), S16.2
unnamed: D19.2 (A), S17.2
unnamed: D20.2 (A), S18.2
unnamed: D21.2 (A), S19.2
unnamed: D23.2 (A), S20.2
unnamed: D24.2 (A), S21.2
unnamed: D25.2 (A), S22.2
unnamed: D26.2 (A), S23.2
unnamed: D27.2 (A), S24.2
unnamed: D28.2 (A), S25.2
unnamed: D29.2 (A), S26.2
unnamed: D30.2 (A), S27.2
unnamed: D31.2 (A), S28.2
unnamed: D32.2 (A), S29.2
unnamed: D33.2 (A), S30.2
unnamed: D34.2 (A), S31.2
unnamed: D35.2 (DOUT), D36.3 (DIN)
unnamed: D36.1 (DOUT), D37.4 (DIN)
unnamed: D37.2 (DOUT), D38.4 (DIN)
unnamed: D38.2 (DOUT), D39.4 (DIN)
unnamed: D39.2 (DOUT), D77.3 (DIN)
unnamed: D40.2 (DOUT), D42.4 (DIN)
unnamed: D40.4 (DIN), D77.1 (DOUT)
unnamed: D41.1 (DOUT), D46.4 (DIN)
unnamed: D41.3 (DIN), D42.2 (DOUT)
unnamed: D43.1 (DOUT), D45.4 (DIN)
unnamed: D43.3 (DIN), D44.2 (DOUT)
unnamed: D44.4 (DIN), D46.2 (DOUT)
unnamed: D45.2 (DOUT), D47.4 (DIN)
unnamed: D47.2 (DOUT), D48.4 (DIN)
unnamed: D48.2 (DOUT), D49.4 (DIN)
unnamed: D49.2 (DOUT), D50.4 (DIN)
unnamed: D50.2 (DOUT), D51.4 (DIN)
unnamed: D51.2 (DOUT), D52.4 (DIN)
unnamed: D52.2 (DOUT), D53.4 (DIN)
unnamed: D53.2 (DOUT), D54.4 (DIN)
unnamed: D54.2 (DOUT), D55.4 (DIN)
unnamed: D55.2 (DOUT), D56.4 (DIN)
unnamed: D56.2 (DOUT), D57.4 (DIN)
unnamed: D57.2 (DOUT), D58.4 (DIN)
unnamed: D58.2 (DOUT), D59.3 (DIN)
unnamed: D59.1 (DOUT), D60.4 (DIN)
unnamed: D60.2 (DOUT), D61.4 (DIN)
unnamed: D61.2 (DOUT), D62.3 (DIN)
unnamed: D62.1 (DOUT), D63.4 (DIN)
unnamed: D63.2 (DOUT), D64.4 (DIN)
unnamed: D64.2 (DOUT), D66.4 (DIN)
unnamed: D65.1 (DOUT), D67.4 (DIN)
unnamed: D65.3 (DIN), D66.2 (DOUT)
unnamed: D67.2 (DOUT), D71.4 (DIN)
unnamed: D70.2 (K), R17.1
unnamed: D71.2 (DOUT), D72.4 (DIN)
unnamed: D72.2 (DOUT), D73.4 (DIN)
unnamed: D73.2 (DOUT), D74.4 (DIN)
unnamed: D74.2 (DOUT), D75.4 (DIN)
unnamed: D75.2 (DOUT), D76.4 (DIN)
unnamed: F1.1, Q3.3 (D), R22.1, U6.3 (-)
unnamed: P1.A5 (CC1), R9.1
unnamed: P1.B5 (CC2), R10.1
unnamed: P1.S1 (SHIELD), R5.2, R6.2
unnamed: P2.S1 (SHIELD), R12.2, R13.2
unnamed: Q3.1 (G), U6.4
unnamed: R18.2, U5.32 (PA11)
unnamed: R19.2, U5.33 (PA12)
PLUG_DETECT: R22.2, R23.1, U5.30 (PA9)
RGB_DATA: D35.4 (DIN), R26.1, U5.31 (PA10)
RGB_VDD: C3.1, C4.1, C5.1, C6.1, C7.1, C8.1, C9.1, C10.1, C11.1, C12.1, C13.1, C14.1, C15.1, C16.1, C17.1, C18.1, C19.1, C20.1, C21.1, C22.1, C23.1, C24.1, C25.1, C26.1, C27.1, C28.1, C29.1, C30.1, C31.1, C32.1, C33.1, C34.1, C35.1, C36.1, C43.1, C48.1, C49.1, C50.1, C51.1, C52.1, C53.1, D35.1 (VDD), D36.4 (VDD), D37.1 (VDD), D38.1 (VDD), D39.1 (VDD), D40.1 (VDD), D41.4 (VDD), D42.1 (VDD), D43.4 (VDD), D44.1 (VDD), D45.1 (VDD), D46.1 (VDD), D47.1 (VDD), D48.1 (VDD), D49.1 (VDD), D50.1 (VDD), D51.1 (VDD), D52.1 (VDD), D53.1 (VDD), D54.1 (VDD), D55.1 (VDD), D56.1 (VDD), D57.1 (VDD), D58.1 (VDD), D59.4 (VDD), D60.1 (VDD), D61.1 (VDD), D62.4 (VDD), D63.1 (VDD), D64.1 (VDD), D65.4 (VDD), D66.1 (VDD), D67.1 (VDD), D71.1 (VDD), D72.1 (VDD), D73.1 (VDD), D74.1 (VDD), D75.1 (VDD), D76.1 (VDD), D77.4 (VDD), F2.2, Q3.2 (S), R2.1, R3.1, R26.2, U2.3 (VI), U6.1 (+), U6.5 (V+)
Rot_A: R1.2, U5.13 (PA3)
Rot_B: R4.2, U5.14 (PA4)
Rot_Row: D22.2 (A), SW1.S1
Row1: D3.1 (K), D8.1 (K), D13.1 (K), D18.1 (K), D23.1 (K), D27.1 (K), D31.1 (K), U5.29 (PA8)
Row2: D4.1 (K), D9.1 (K), D14.1 (K), D19.1 (K), D24.1 (K), D28.1 (K), D32.1 (K), U5.25 (PB12)
Row3: D5.1 (K), D10.1 (K), D15.1 (K), D20.1 (K), D25.1 (K), D29.1 (K), D33.1 (K), U5.16 (PA6)
Row4: D1.1 (K), D6.1 (K), D11.1 (K), D16.1 (K), D21.1 (K), D26.1 (K), D30.1 (K), D34.1 (K), U5.15 (PA5)
Row5: D2.1 (K), D7.1 (K), D12.1 (K), D17.1 (K), D22.1 (K), U5.11 (PA1)
USART3_RX: JP1.1 (A), JP2.1 (A), U5.22 (PB11)
USART3_TX: JP1.3 (B), JP2.3 (B), U5.21 (PB10)
USB_D+: P1.A6 (D+), P1.B6 (D+), R19.1, R20.1, U3.3 (I/O2)
USB_D-: P1.A7 (D-), P1.B7 (D-), R18.1, U3.1 (I/O1)
USB_VBUS: F1.2, P1.A4 (VBUS), P1.A9 (VBUS), P1.B4 (VBUS), P1.B9 (VBUS), U3.5 (VBUS)
USB_VBUS_IN_FUSED: C45.2, F2.1, P2.A4 (VBUS), P2.A9 (VBUS), P2.B4 (VBUS), P2.B9 (VBUS), U4.5 (VBUS)
VDD: C37.1, C38.1, C39.1, C41.1, C44.1, C54.1, D70.1 (A), J1.6, P3.3, R7.1, R8.1, R14.1, R20.2, R24.1, S32.2, U1.8 (VCC), U2.2 (VO), U5.1 (VBAT), U5.9 (VDDA), U5.24 (VDD), U5.36 (VDD), U5.48 (VDD)
VSS: C1.2, C2.2, C3.2, C4.2, C5.2, C6.2, C7.2, C8.2, C9.2, C10.2, C11.2, C12.2, C13.2, C14.2, C15.2, C16.2, C17.2, C18.2, C19.2, C20.2, C21.2, C22.2, C23.2, C24.2, C25.2, C26.2, C27.2, C28.2, C29.2, C30.2, C31.2, C32.2, C33.2, C34.2, C35.2, C36.2, C37.2, C38.2, C39.2, C41.2, C42.2, C43.2, C44.2, C45.1, C46.2, C47.2, C48.2, C49.2, C50.2, C51.2, C52.2, C53.2, C54.2, D35.3 (VSS), D36.2 (VSS), D37.3 (VSS), D38.3 (VSS), D39.3 (VSS), D40.3 (VSS), D41.2 (VSS), D42.3 (VSS), D43.2 (VSS), D44.3 (VSS), D45.3 (VSS), D46.3 (VSS), D47.3 (VSS), D48.3 (VSS), D49.3 (VSS), D50.3 (VSS), D51.3 (VSS), D52.3 (VSS), D53.3 (VSS), D54.3 (VSS), D55.3 (VSS), D56.3 (VSS), D57.3 (VSS), D58.3 (VSS), D59.2 (VSS), D60.3 (VSS), D61.3 (VSS), D62.2 (VSS), D63.3 (VSS), D64.3 (VSS), D65.2 (VSS), D66.3 (VSS), D67.3 (VSS), D71.3 (VSS), D72.3 (VSS), D73.3 (VSS), D74.3 (VSS), D75.3 (VSS), D76.3 (VSS), D77.2 (VSS), HSE1.2, HSE1.4, J1.1, MH1.1, MH2.1, MH3.1, MH4.1, MH5.1, MH6.1, MH7.1, MH8.1, MH9.1, P1.A1 (GND), P1.A12 (GND), P1.B1 (GND), P1.B12 (GND), P2.A1 (GND), P2.A12 (GND), P2.B1 (GND), P2.B12 (GND), P3.4, Q1.2 (S), R5.1, R6.1, R9.2, R10.2, R11.2, R12.1, R13.1, R17.2, R23.2, R25.2, R27.2, SW1.C, U1.1 (A0), U1.2 (A1), U1.3 (A2), U1.4 (GND), U1.7 (WP), U2.1 (GND), U3.2 (GND), U4.2 (GND), U5.8 (VSSA), U5.23 (VSS), U5.35 (VSS), U5.47 (VSS), U6.2 (V-)

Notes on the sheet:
Switch Matrix
Rotary Encoder
Mounting Holes
Split Comms
USB Connection
Decoupling Capacitors
External HSE Clock
CLOAD = 2 * (CLOAD_CRYSTAL - CPARASITIC) CPARASITIC = 2pF
f(-3db) = 1 / (2 * pi * C * R)
SWD / JTAG Interface
Display provides pull-up resistors
OLED Display
Input Voltage Regulator
I2C EEPROM
ESD protection
RGB Leds and Decoupling Capacitors
JLC PCBA Holes
YAEMK Logos
MCU STM32F303 or GD32VF103
Populate R24 when board is the left side. Populate R25 when board is the right side.
Handness Selection
Discrete ideal diode. Provides ultra low voltage drop and zero reverse current.
Fuses and plug detect
Reset and DFU Bootloader Circuit
Short Press for Reset Long Press for DFU Bootloader

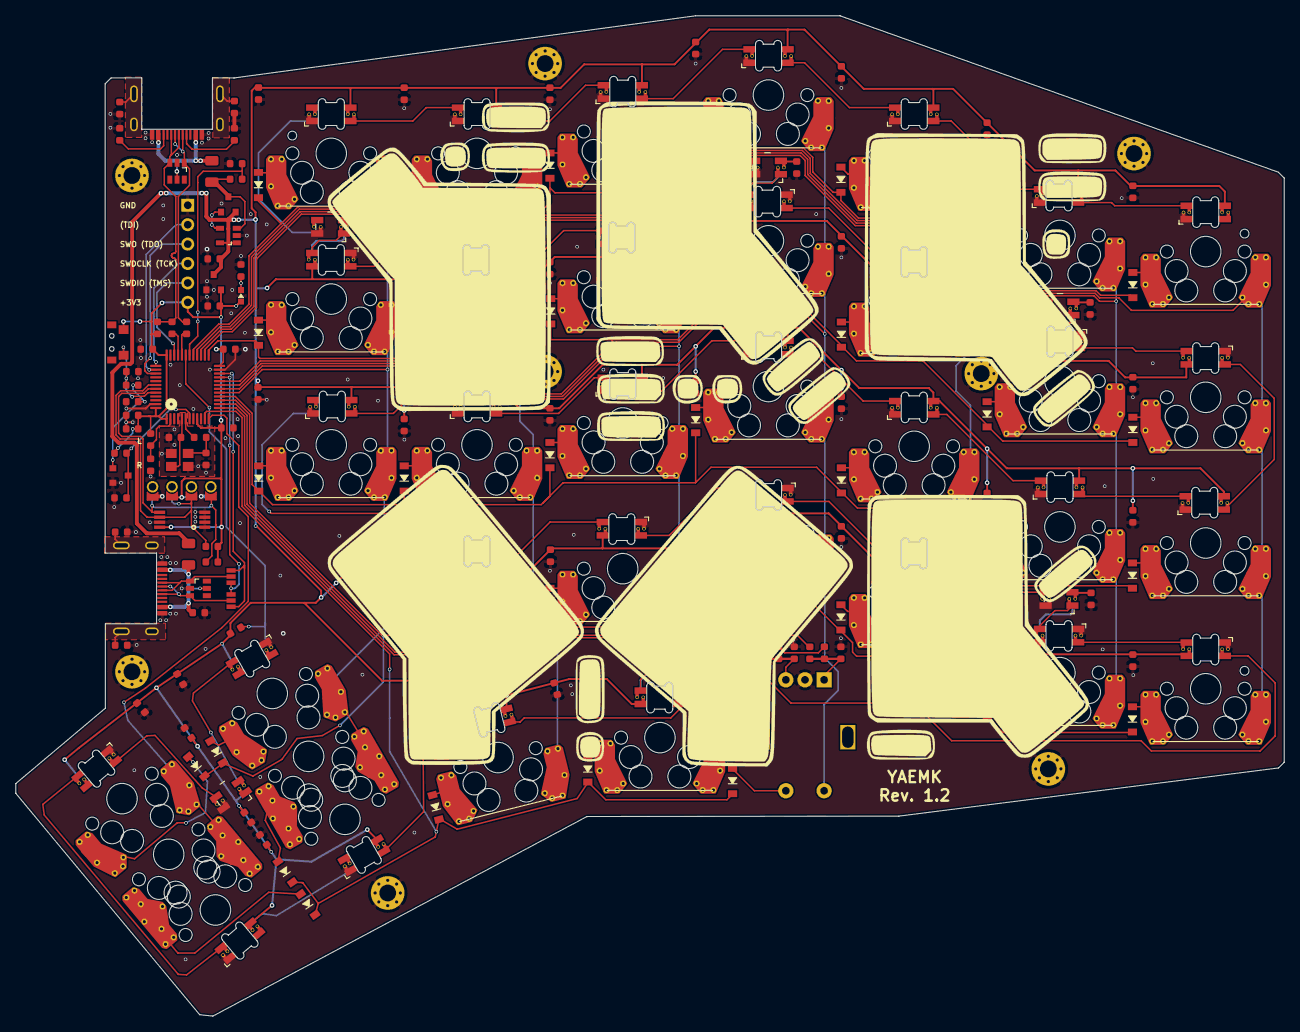
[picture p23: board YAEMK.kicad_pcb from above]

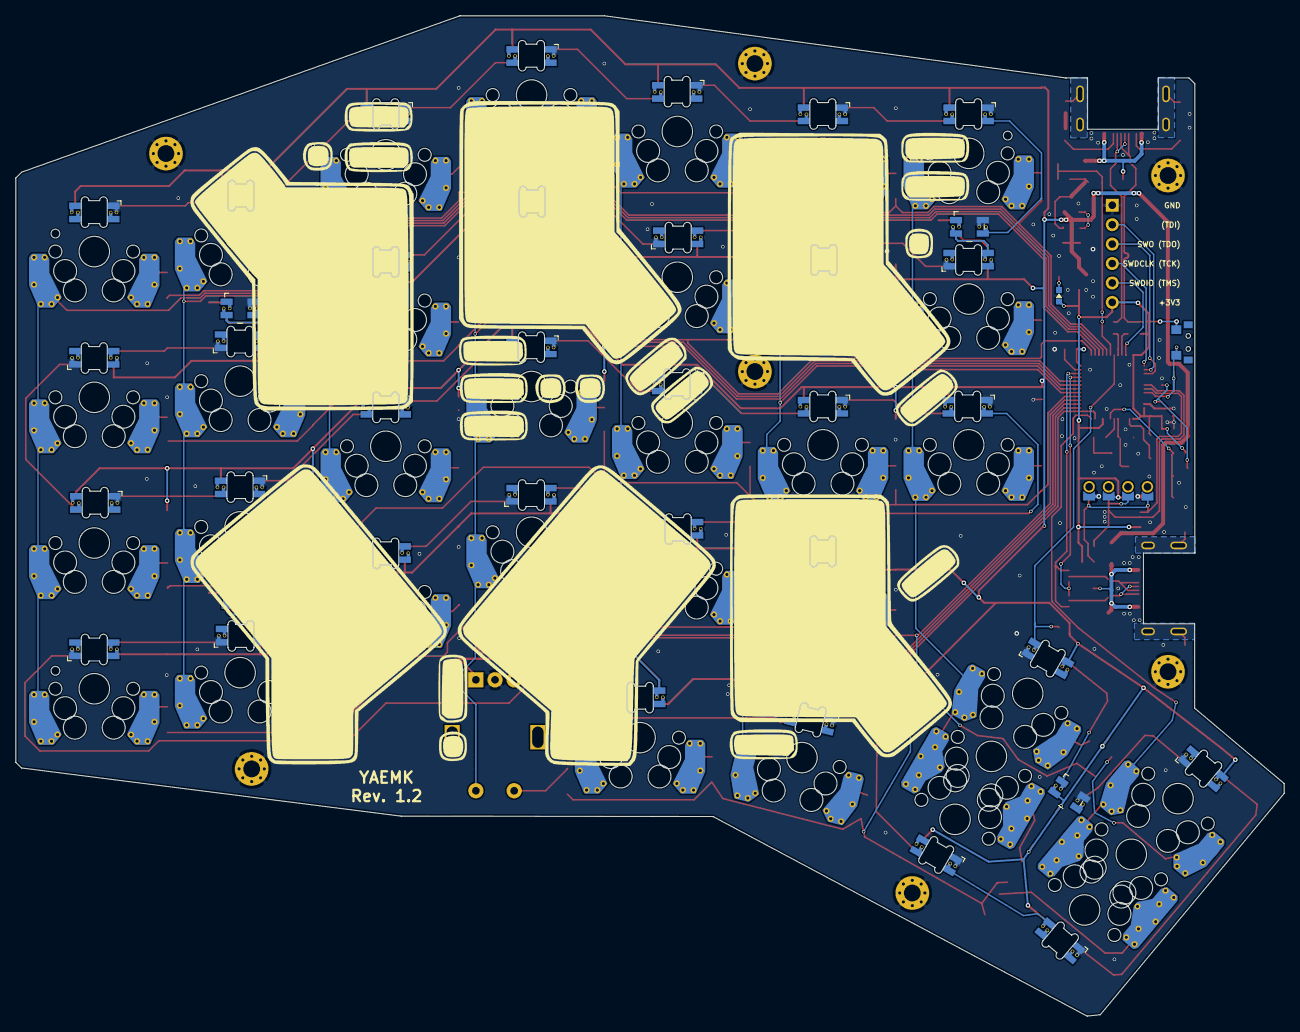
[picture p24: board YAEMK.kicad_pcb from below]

Board: 2 copper layers, 165.8 x 130.8 mm, 218 parts (3 on the bottom side), 125 nets.

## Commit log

2020-08-13 Add YAEMK 1.1 Schematics and PCB
    [YAEMK-B_Mask.gbr, YAEMK-B_SilkS.gbr, YAEMK-Back.gbr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]
2020-08-13 Add notes about pull-up resistors
    [mcu.sch]
2020-11-04 Update Footprints for easy Case creation
2020-12-18 Add WIP yaemk 1.2 files
    [BOM.xlsx, BOM_LCSC_10.xlsx, YAEMK.kicad_pcb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]
2020-12-18 Update YAEMK
    [YAEMK.kicad_pcb, YAEMK.sch, mcu.sch]
2020-12-18 Update YAEMK 1
    [YAEMK.kicad_pcb, ledmatrix.sch, mcu.sch]
2020-12-18 One step further
    [YAEMK.kicad_pcb, YAEMK.sch, ledmatrix.sch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]
2020-12-18 Correct RGB DATA
    [YAEMK.kicad_pcb, ledmatrix.sch, mcu.sch]
2020-12-18 YAEMK 1.2 RC
    [YAEMK-B_Mask.gbr, YAEMK-B_SilkS.gbr, YAEMK-Back.gbr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]
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2020-12-18 Update Footprints on PCB
    [YAEMK.kicad_pcb]
2020-12-18 Clean up save point
    [BOM.xlsx, BOM_LCSC_10.xlsx, YAEMK.kicad_pcb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]
2020-12-18 Add Ideal Diode switch to LDO
    [YAEMK.sch]
2020-12-18 LDO and ideal diode layout
    [YAEMK.kicad_pcb, YAEMK.sch]
2020-12-18 Add another underglow LED
    [YAEMK.kicad_pcb, YAEMK.sch]
2020-12-18 Update Display
    [YAEMK.kicad_pcb]
2020-12-18 Update sot23-6 footprint
    [YAEMK.kicad_pcb]
2020-12-18 Remove text items
    [YAEMK.kicad_pcb]
2020-12-18 Clearance of MX Footprint
    [YAEMK.kicad_pcb]
2020-12-18 position display
    [YAEMK.kicad_pcb, YAEMK.sch]
2020-12-18 RGB LED soldermask indicator
    [YAEMK.kicad_pcb]
2020-12-18 Silkscreen fixes
    [YAEMK.kicad_pcb, YAEMK.sch]
2020-12-18 Generate Gerbers and Add LCSC Part Numbers
    [YAEMK-B_Mask.gbr, YAEMK-B_SilkS.gbr, YAEMK-Back.gbr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]
2020-12-18 Correct Diode Footprint add JLC assembly holes
    [YAEMK.kicad_pcb, YAEMK.sch]
2020-12-18 Add assembly holes for real
    [YAEMK.kicad_pcb, YAEMK.sch]
2020-12-18 Add logos as symbols, clean up symbols
    [YAEMK.kicad_pcb, YAEMK.sch]
2020-12-18 Remove WS2812 from mx symbols
    [YAEMK.kicad_pcb, YAEMK.sch]
2020-12-18 Remove WS2812 Leds from mx symbols
    [YAEMK.kicad_pcb, YAEMK.sch]
2020-12-18 Cleanup Schematic
    [YAEMK.kicad_pcb, YAEMK.sch]
2020-12-18 Generate Gerber Files
    [YAEMK-B_Mask.gbr, YAEMK-B_SilkS.gbr, YAEMK-Back.gbr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]
2020-12-18 Add updated interactive bom
    [YAEMK.kicad_pcb, YAEMK.sch]
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2020-12-18 Remove obsolete Case Files
2021-02-01 Update Reset / DFU circut to single button version
    [YAEMK.kicad_pcb, YAEMK.sch]
2021-02-01 Update Gerbers
    [YAEMK-B_Mask.gbr, YAEMK-B_SilkS.gbr, YAEMK-Back.gbr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]
2021-02-01 Update Plugdetect Values
    [YAEMK.kicad_pcb, YAEMK.sch]
2021-02-01 Add opamp ideal diode
    [YAEMK.kicad_pcb, YAEMK.sch]
2021-02-01 RC for real
    [YAEMK-B_Mask.gbr, YAEMK-B_SilkS.gbr, YAEMK-Back.gbr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]
2021-02-06 Update ESD Diode, clean libs
    [YAEMK-B_Mask.gbr, YAEMK-B_SilkS.gbr, YAEMK-Back.gbr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]
2021-02-06 Add assembly files
    [YAEMK-top-pos_corrected.csv, YAEMK_bom.csv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]
2021-02-09 Add all case variants
2021-04-08 Add 0.1mm kerf case files
2021-04-08 Add GD32VF103 to schematic
    [YAEMK.sch]
2021-04-08 Add notes about the case
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2021-04-08 Add image before case
2021-04-09 Add raw pcb scans
2021-04-09 Add pcb image with assembly steps
    [YAEMK.kicad_pcb]
2021-04-09 Add case instructions and picture
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2021-04-10 Update BOM and ordering process for YAEMK
    [YAEMK_bom.csv]
2021-04-10 Give M3 insert thicker diameter
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2021-04-12 Rename top plate files to match build guide
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2021-04-14 Update top plates
    * add rounded corner to switch cutout
    * 0.1mm kerf plates were really 0.05mm and only on one side...
    * 0.1mm kerf cutouts live on comments layer
    * no kerf cutouts live on eco1 layer
    [YAEMK.kicad_pcb]
2021-04-15 Update case files take 2
    * All top plates feature a cutout of 13.9 x 13.9 to clamp the switches thightly
    * Switch cutouts feature a small rounded corner
    * Shrink SVG size do drawing area
    * 0.1mm kerf means 0.05mm extra on both sides not 0.1mm
    [YAEMK.kicad_pcb]
2021-04-15 Replace discontinued led with blue one
    [YAEMK.sch]
2021-04-15 Update pinheader not on backorder
    [YAEMK.sch]
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2021-09-15 Update JLC BOM with correct header
    [YAEMK_bom.csv]
2021-09-15 Minor fixes to EEPROM comments in schematic
    [YAEMK.sch]
2021-09-15 Add alternate BOM with alternative EEPROM and OPAMP
    Global semi-conductor shortage going strong.
    [YAEMK_bom_alternate_eeprom_and_opamp.csv]
2021-09-15 Add note about tenting legs and alternate bom
2021-11-17 Fixes assembly licensing info
2021-12-21 Specifies which KiCad mods are from Stefan (thx stefan!)
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2023-05-31 docs: update link to LCSC shipping policy
    Unfortunately, they changed shipping policy and now it's not
    possible to combine PCB and components order. However, there's still
    discount for shipping. They say that you need an account registered
    before Mar. 12th 2019, which I have. I haven't checked if there's no
    discount for newly created accounts
    As there's still possibility for discount update the link with
    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
2023-06-01 docs: add links for components without link
    I ordered those myself, both Gateron sockets and keycaps from these
    stores are of really good quality.
2023-06-01 docs: change pad orientation description to more clear one
    On most photos the board are shown in the way that jumpers are
    vertical. Moreover, the board can be rotated in both ways so it's
    quite confusing which pad is left and which one is right.
    Change pad position to top and bottom ones as seen on photos.
2023-06-01 docs: unify DFU switch name with website
    The switch is called "Reset/DFU switch" on the website. Also, the
    "+" sign is quite confusing as there's only one switch.
    Unify the name of the switch with one used on website.
2023-06-01 docs: more details in flashing manual
    The fact that board doesn't register at all as USB devices is a
    little confusing and made me look for hardware problems. Mentioning
    that without firmware MCU won't register as a USB devices would
    help.
    My STM showed up as 2 DFU interfaces. I found that with intf and alt
    one can uniquely identify flash memory. Add a command and
    explanation how to achieve this.
2023-06-25 docs: add note on how to test LEDs
    This is handy note. Clarifies if LEDs are suppose to work at all
    with testing firmware or any of them is dead.
2023-06-25 docs: add schematic of the LED chain for easier testing
    I found myself constantly looking for LED order. This helps when you
    have a dead LED and don't know which one it is. Solve this by adding
    chain connection schematic.
